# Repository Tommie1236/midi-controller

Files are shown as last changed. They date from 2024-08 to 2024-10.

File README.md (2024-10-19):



<!--[![render drawio](https://github.com/Tommie1236/midi-controller/actions/workflows/render-drawio.yml/badge.svg)](https://github.com/Tommie1236/midi-controller/actions/workflows/render-drawio.yml)-->

### huge thanks to the amazing [rp2040 skeleton project](https://github.com/daveythacher/RP2040_SKELETON). it helped immensly setting up this project. i probably couldn't have done it without

# &lt;still need good name :)&gt;
#### A lighting focused midi controller

---
### Why?
I started this project as i wanted phisical controls to go with the [mydmx3](https://www.adj.com/mydmx-3) dmx controller software.  
Mydmx3 practicly only support midi as data in/out next to dmx out. So a midi controller it is.  
There are more than enough midi controllers on the market but almost all of them are audio focused in the controls. I couldn't really vind any that i would like for controlling lighting. So i decided to design and build my own.

### Requirements
I set a couple of requirements that i definetly wanted in my controler. As following:  
#### Controls:

- **motorized faders**. Mostly for dimming controls, enough in the playback section and 1 as Master.  
  I chose motorized so they could sync with the controlling software if the value changes and for for example if you were to switch banks to a new set of controls. (mydmx doesn't support that but i wanted to design my controller to work with almost anything.)

- **Buttons**. for playbacks/executors en general control, a whole lot.  
  Of Course. what would a controller be without a lot of buttons. I also want them to have black with transparent text keycaps and rgb leds below to show the status of the button.

- **Encoders**. Mostly speed control but could also be dimmer, at least 1 per "channel"/collumn and a couple spare.
  I wanted some encoders to be able to change the speed of scene/cue playbacks. But also for for example a dimmer channel dat isn't changed often but often enough to have phisical controls for.

- **Small Displays/Scribble Strips**. channel/collumn names, one per channel/collumn.  
  To show what cue/scene was mapped to that channel/collumn. If i implement bank switching inside the controller (as mydmx doesn't support like anything. only the most basic midi triggering) i want to see what cue i have mapped on that fader/buttons.
  And maybe also to show the fader/encoder value when changing. For if you want it to a specific value and the visual position isn't enough.

- **Keypad**. just one, numbers 0-9 + some modifiers.  
  Should speak for itself. just general number inputs and modifiers.

- **"Master" Display**. (relatively) big display, just one.  
   A around 3a4" touch display for configuration of the controller and general info. Main controls for anything happening inside the controller.

- **Leds**. A lot. most RGB some just Amber.  
  I want all the buttons to have a seperate controllable RGB led to show the buttons status. and about 16 mono Amber leds around the encoders to show their value.

#### Conectivity:

- **usb midi**. one usb-B port.
  To connect to a pc running for example mydmx.

- **hardware midi**. 2 or 3 din-5 ports.
  To connect to other midi gear or any controller that has hardware midi ports on it. Should have the same data as the usb midi port

- **External Switch Ports**. 2a3 x 1/4" jack.
  To connect external footswitches or pedals. should support normal on/off footswitches and maybe one or 2 can have analog value support.

- **Desk Light**. xlr-4?.
  A xlr connector that support a lot of desk lights. preferably xlr-4 so it isn't confused with audio or dmx signals. Sadly there isn't a standard for desk ligths as far as i can find.

- **Powercon Socket**. Blue one. maybe also power out.  
  Of cource. It needs some power to run. prefereably powercon (true1??) but a C14 socket would also work.  
  with the motor faders and a lot of leds. Usb supplied power wont be enough.

#### And here are some features i want to support but arent required for the mvp: 

- **USB Hub**. Probably USB-A sockets.  
  To connect more devices downstream from the controller

- **RTP MIDI**. Wifi/Ethernet  
  Using a ESP32 or similar to handle the network stack and enable the controller to communicate either wireless or via a ethernet cable.  
  Adding to the already available midi connection options of USB-MIDI and hardware-MIDI

- **Web Server**.  
  Maybe a configuration webserver as the display will be quite small. would also run on the ESP32 that handels the network.  
  it connects to the main rp2040 using uart.

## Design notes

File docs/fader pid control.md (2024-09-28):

https://tttapa.github.io/Pages/Arduino/Control-Theory/Motor-Fader/PID-Controllers.html

currently using exactly the same values so can probably just ~~steal~~ uhmmm, use those parameters

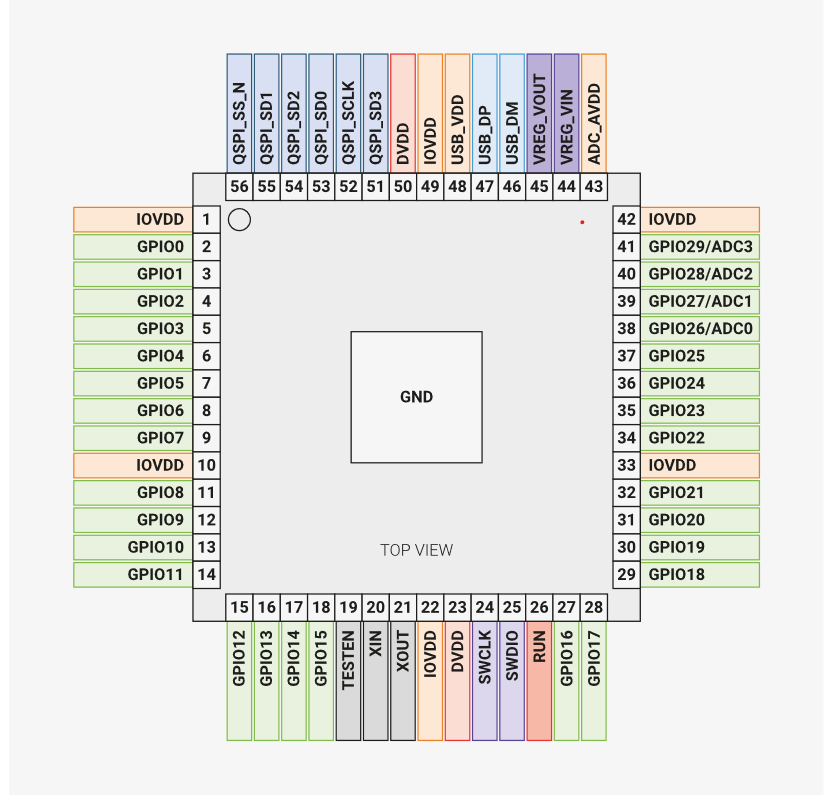
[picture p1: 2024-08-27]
docs/rp2040-pinout.png

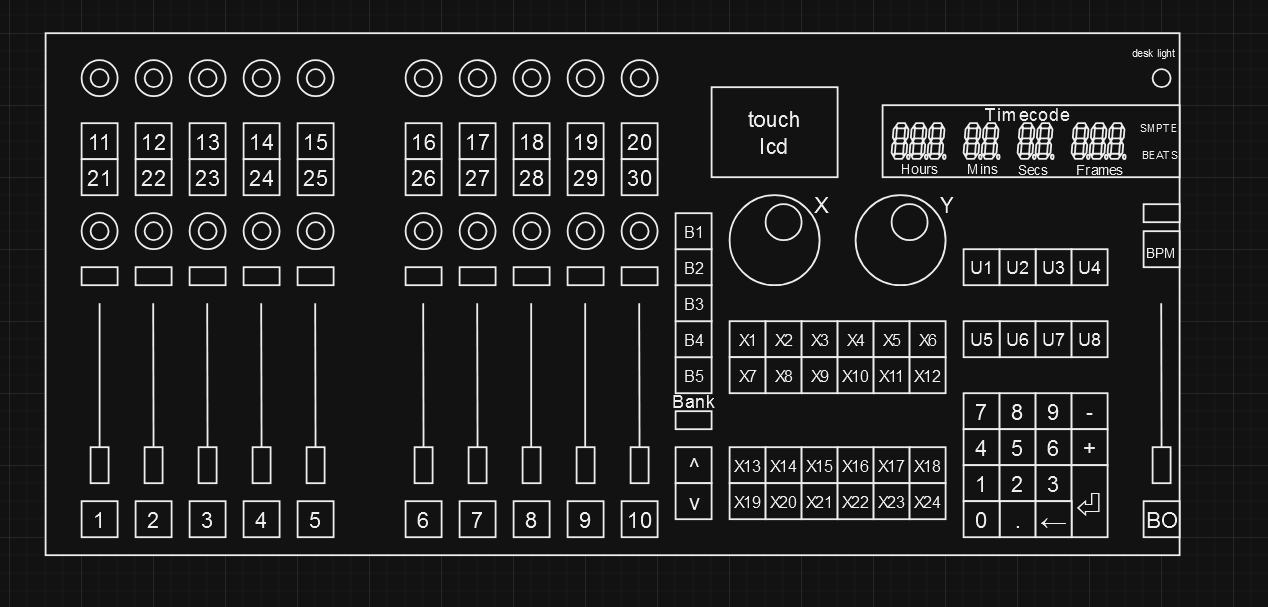
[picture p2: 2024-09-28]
model/Screenshot 2024-09-28 132856.png

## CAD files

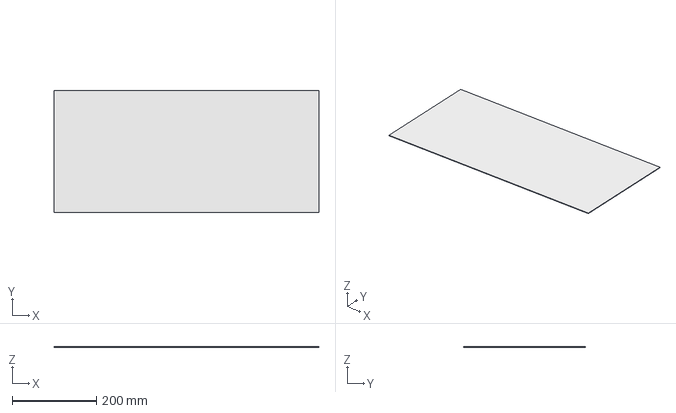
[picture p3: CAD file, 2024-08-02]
docs/model.FCStd
630.0 x 290.0 x 1.50 mm

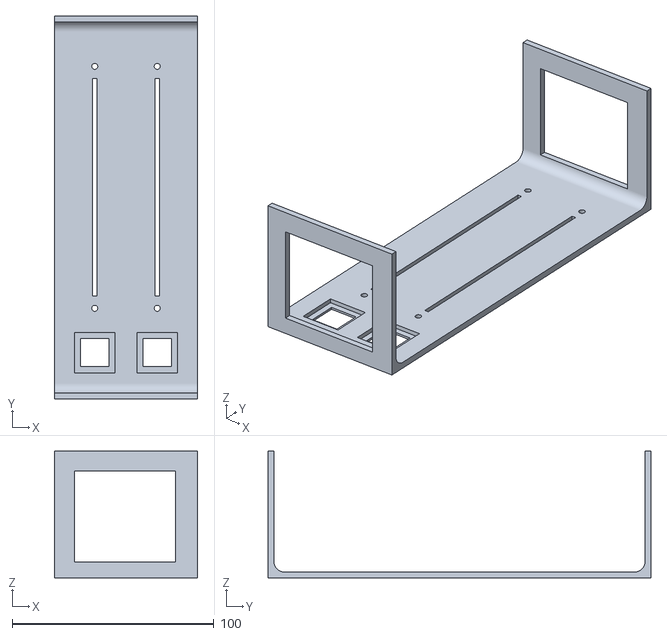
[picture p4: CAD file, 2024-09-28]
model/fader/fader test stand-Body.stl
71.0 x 190.0 x 63.0

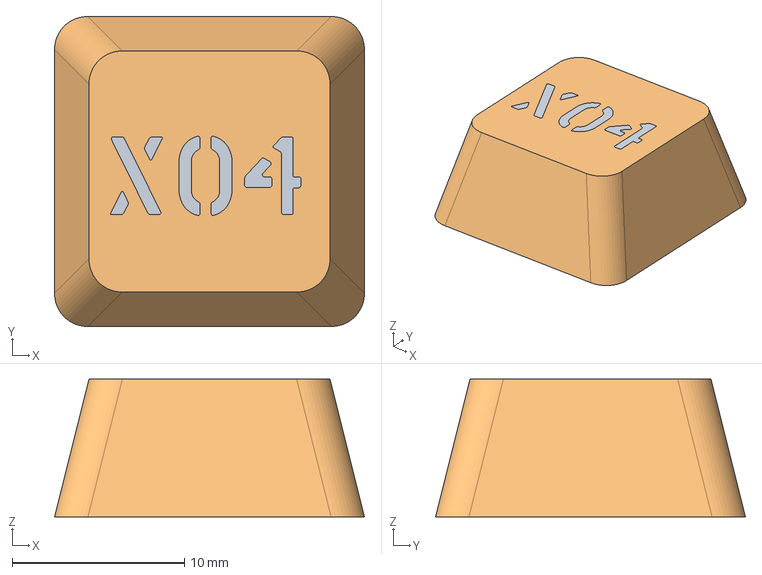
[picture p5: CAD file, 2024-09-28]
model/keycaps/keycap 1u X04.FCStd
18.0 x 18.0 x 8.00 mm

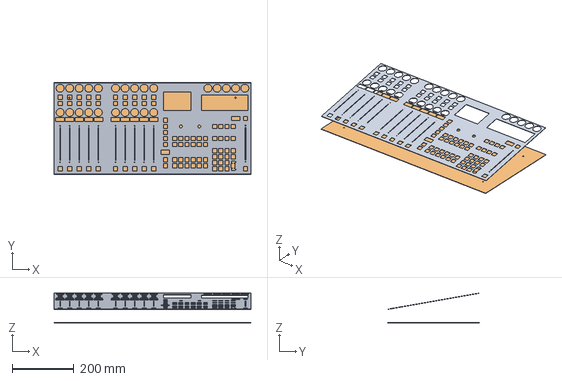
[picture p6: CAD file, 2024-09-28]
model/model.FCStd
640.0 x 300.0 x 97.0 mm
faceplate
bottom

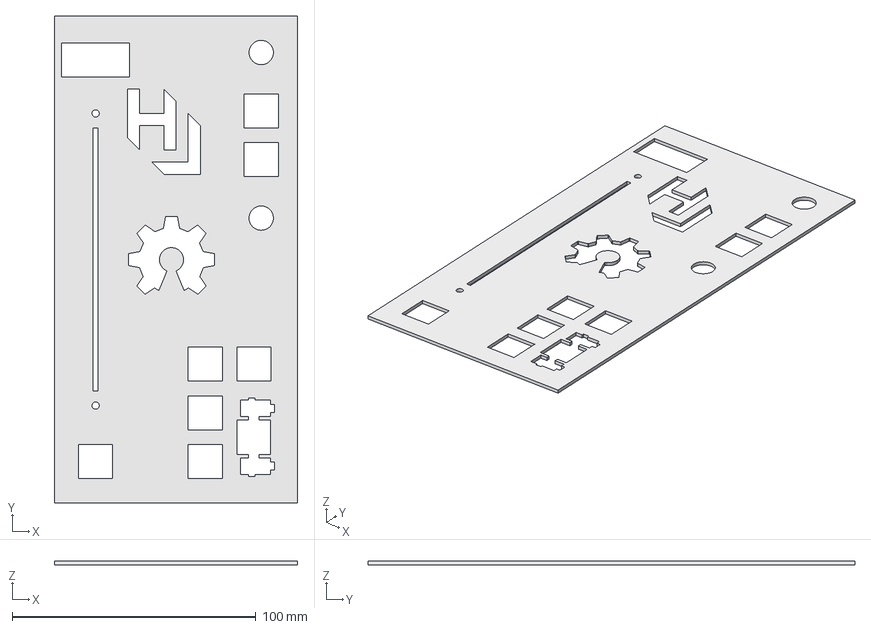
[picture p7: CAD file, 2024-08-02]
model/test/midi-test-Body.step
100.0 x 200.0 x 1.50 mm

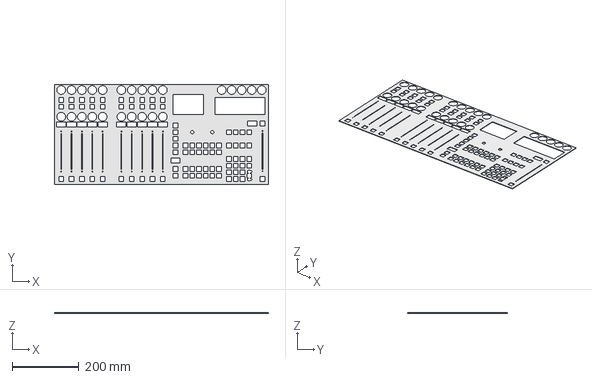
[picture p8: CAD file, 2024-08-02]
model/model-faceplate.step
640.0 x 300.0 x 1.50 mm

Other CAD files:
model/fader/fader test stand.FCStd
model/keycaps/keycap 1u X15.FCStd
model/test/midi-test.FCStd
model/keycaps/keycap 1u X12.FCStd
model/keycaps/keycap 1u X03.FCStd
model/keycaps/keycap 1u X21.FCStd
model/keycaps/keycap 1u X20.FCStd
model/keycaps/keycap 1u X05.FCStd
model/keycaps/keycap 1u X17.FCStd
model/keycaps/keycap 1u X09.FCStd
model/keycaps/keycap 1u X19.FCStd
model/keycaps/keycap 1u X10.FCStd
docs/model-old.FCStd
model/keycaps/keycap 1.stl
model/keycaps/keycap 1u +.FCStd
model/keycaps/keycap 1u -.FCStd
model/keycaps/keycap 1u 0.FCStd
model/keycaps/keycap 1u 1.FCStd
model/keycaps/keycap 1u 10.FCStd
model/keycaps/keycap 1u 11.FCStd
model/keycaps/keycap 1u 12.FCStd
model/keycaps/keycap 1u 13.FCStd
model/keycaps/keycap 1u 14.FCStd
model/keycaps/keycap 1u 15.FCStd
model/keycaps/keycap 1u 16.FCStd
model/keycaps/keycap 1u 17.FCStd
model/keycaps/keycap 1u 18.FCStd
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

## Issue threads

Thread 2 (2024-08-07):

[feature] PID control for the motor faders

Tommie1236, 2024-08-07:
motor faders barely work at half the voltage/speed they are designed for.
if run with higher than 5v (should be 10 and testing at 12) they have a difficult time reaching the correct location and just vibrate because of overshooting the location.

so speed control with pwm and if possible PID.

Tommie1236, 2024-08-22:
decided to use a separate mcu for the fader wings.
cause otherwise all the pid control/feedback had to go through 3+ levels of gpio expanders

now using something like a rp2040 on each wing that is directly connected to whatever is needed for the pid. that should also decreade the time needed/complexity for the other controls on that wing.

Tommie1236, 2024-09-04:
https://tttapa.github.io/Pages/Arduino/Control-Theory/Motor-Fader/index.html

this one uses the exact same faders as i use. so i can probably just "steal" this code and pid parameters.

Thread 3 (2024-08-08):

[calibration] faders and touchscreen.

Tommie1236, 2024-08-08:
pretty nessesary feature. especially for the display. the motor fader would be aproximately correct most of the time and isn't that big of a problem when of by a little.

calibrate with a control sequence. for the display a couple of targets to top.
for the faders put all faders to 0, 20, 50, 80, 100% and go to next value

Tommie1236, 2025-01-05:
also auto pid calibration for faders if possible

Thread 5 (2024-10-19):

TODO

Tommie1236, 2024-10-19:
-[ ] (all) add power circuitry
-[ ] (main) add sub fader board connections
-[ ] (usb) add over current sense and power switch to external usb ports
-[ ] (usb) how connect shield to gnd?
-[ ] (midi) figure out what to do with footswiches/pedal
-[ ] (fader) move display and drive circuitry to 4xx pcb, change all references in schematic/pcb
-[ ] (fader) add display backlight drivers
-[ ] (fader) add mainboard connections
-[ ] (fader) pca 9635 (u306) i2c address
-[ ] (fader) bank/bpm display connections
-[ ] (fader) update fader-encoder connections (add display dc line)
-[ ] (fader) finish routing top pcb, mainly spi bus
-[ ] (fader) how drive encoder dot leds?
-[ ] (encoder) add pcb for 5 top encoders

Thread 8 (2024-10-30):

(encoder) add pcb for 5 top encoders

Tommie1236, 2024-10-30:
- 5 push encoders
  - 15 pins, probably 1x mcp23s17.
  One spare pin. Could add one more general button. or think of specific action.
- 5 led rings (85 pins)
  - 85 pins. 6x tlc59282
  11 spare pins.

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

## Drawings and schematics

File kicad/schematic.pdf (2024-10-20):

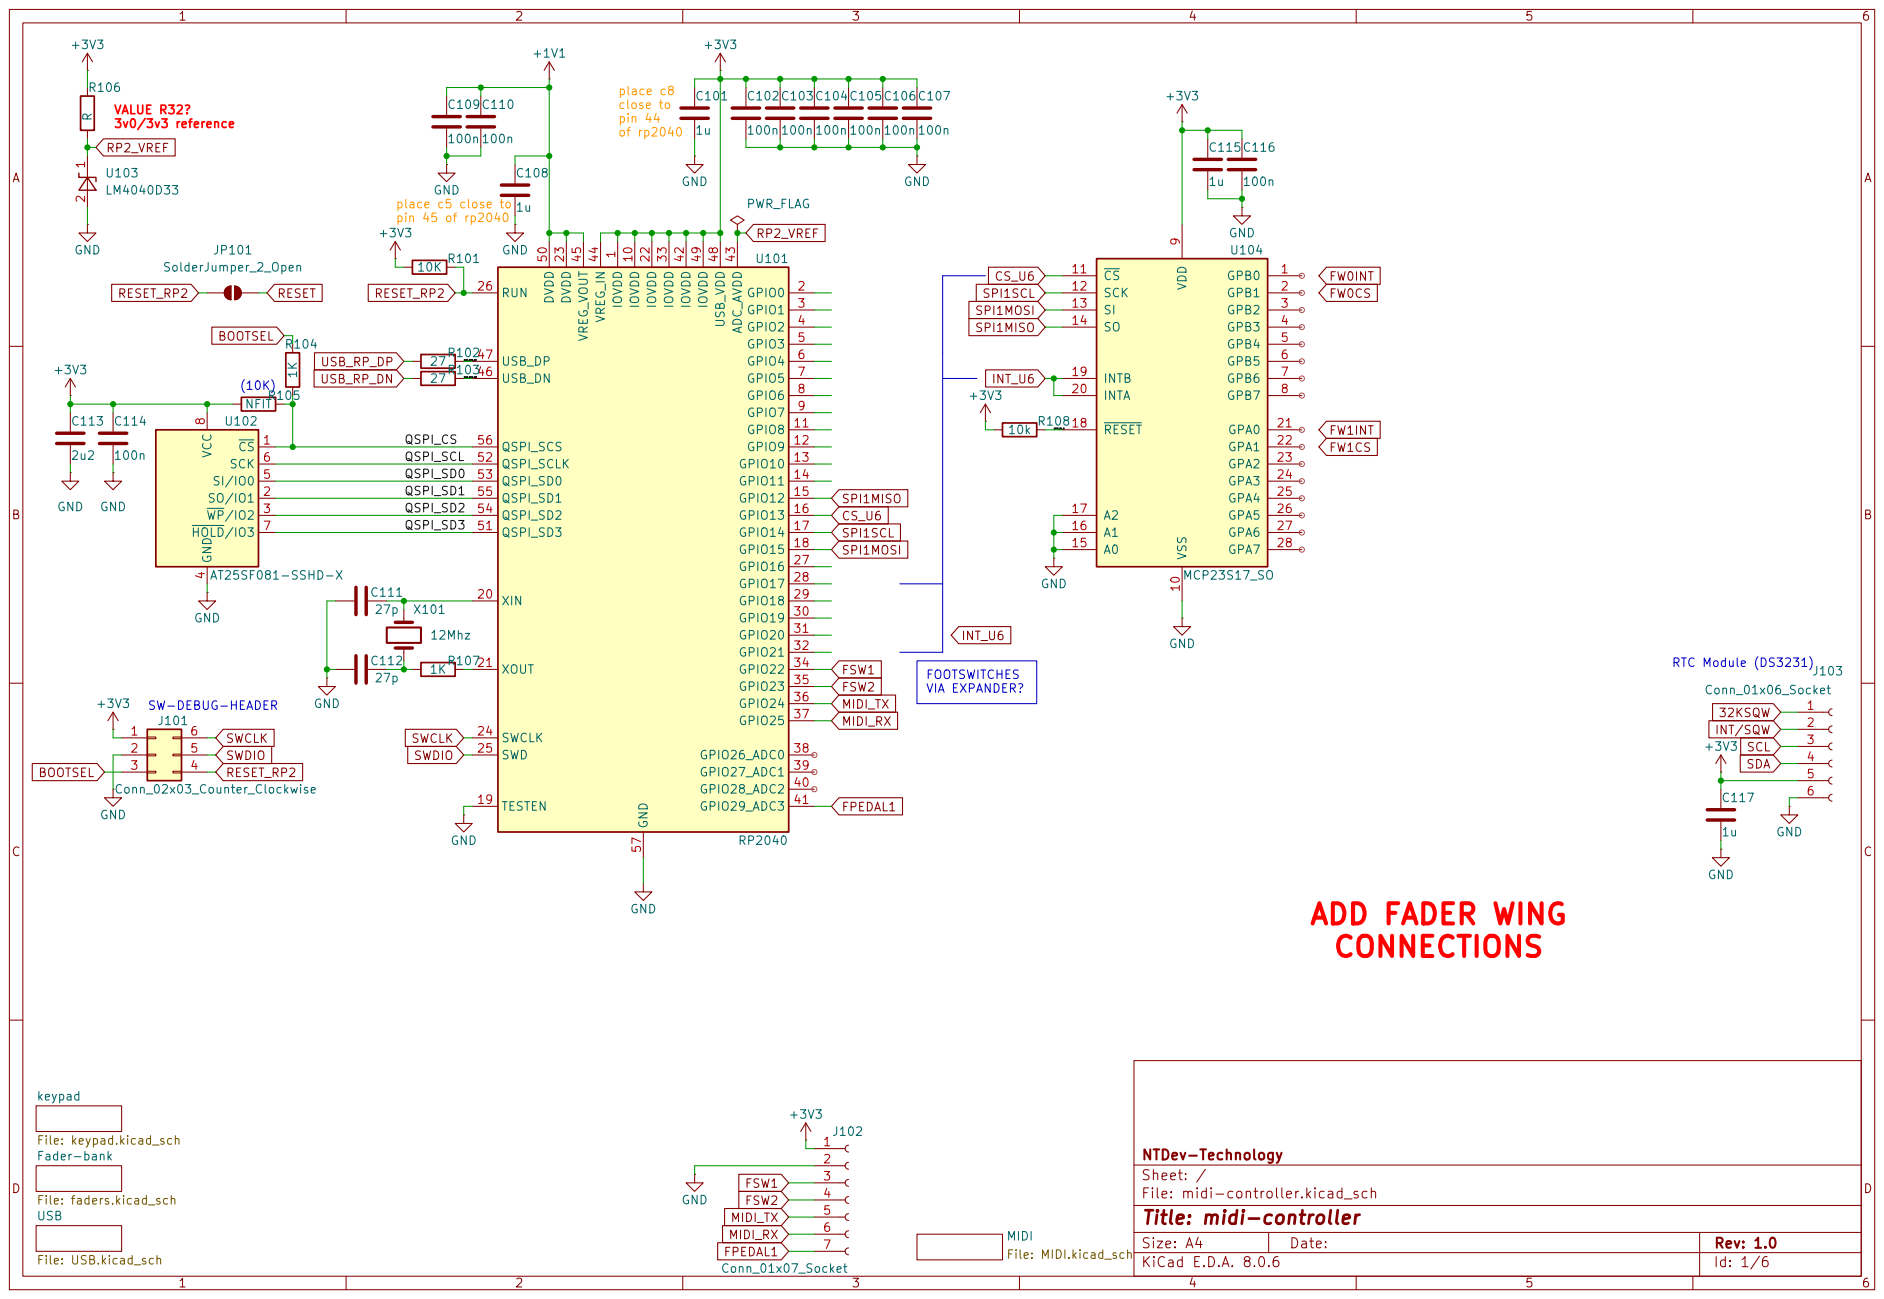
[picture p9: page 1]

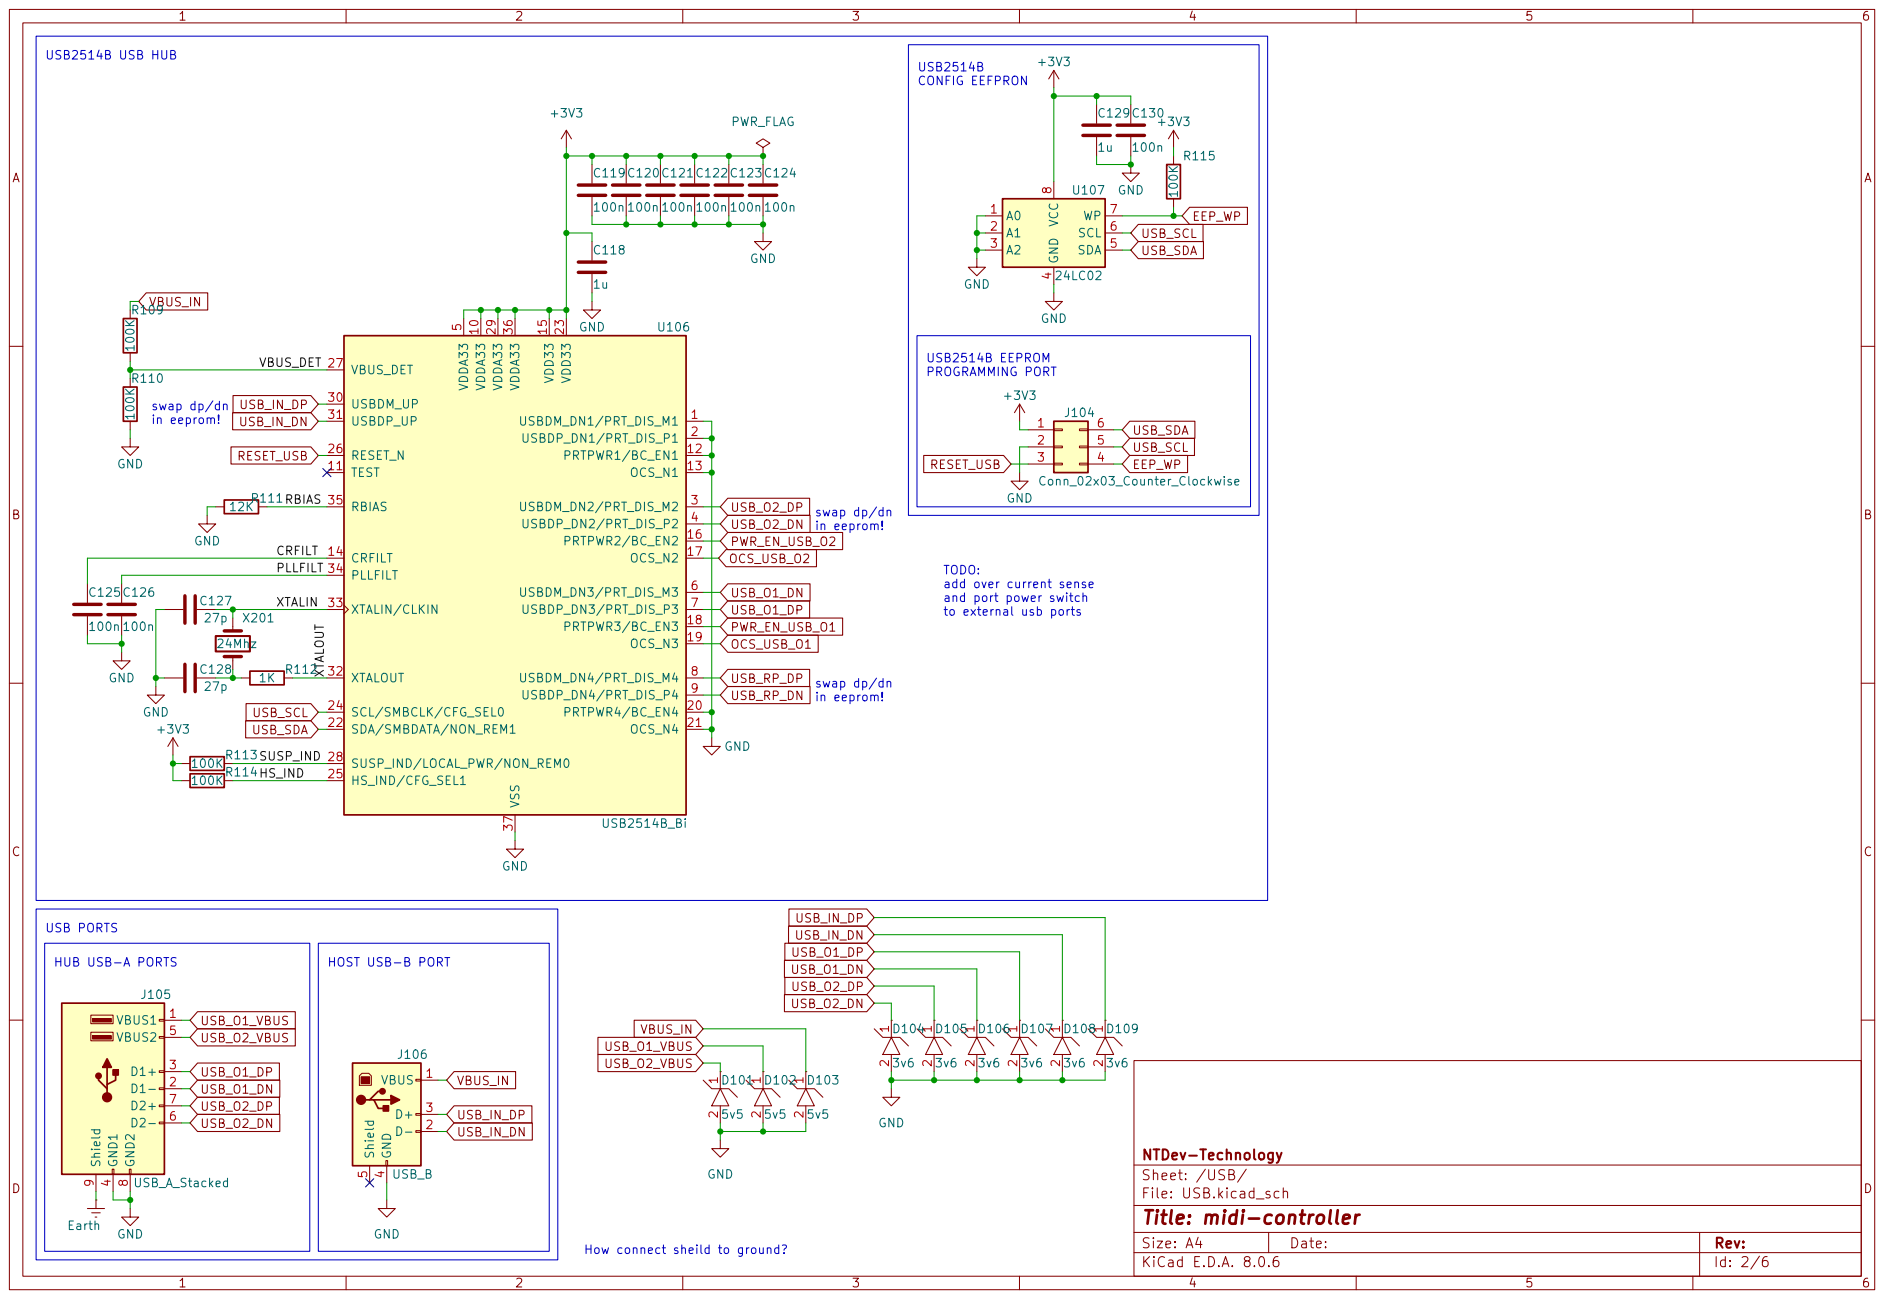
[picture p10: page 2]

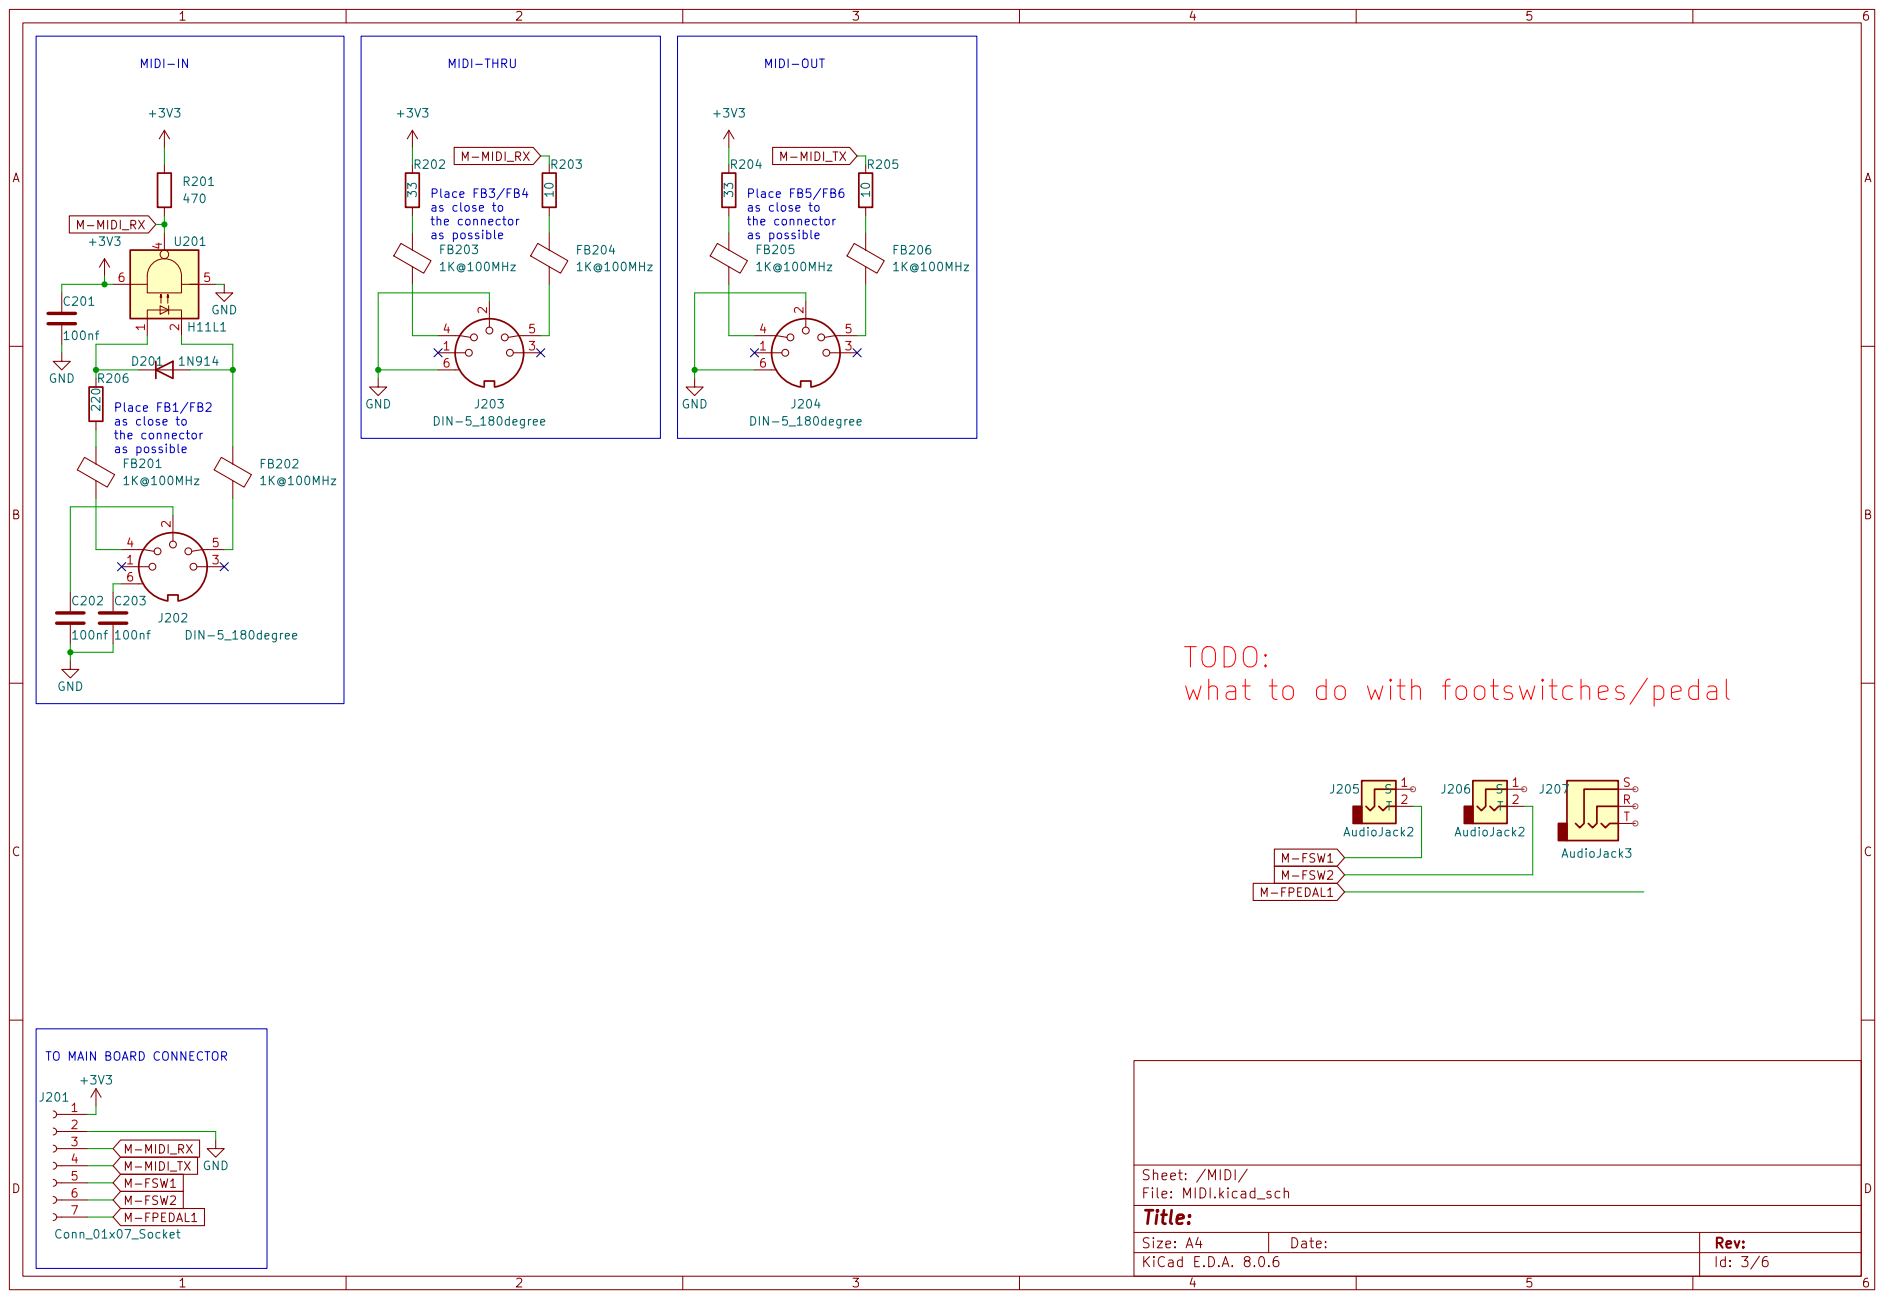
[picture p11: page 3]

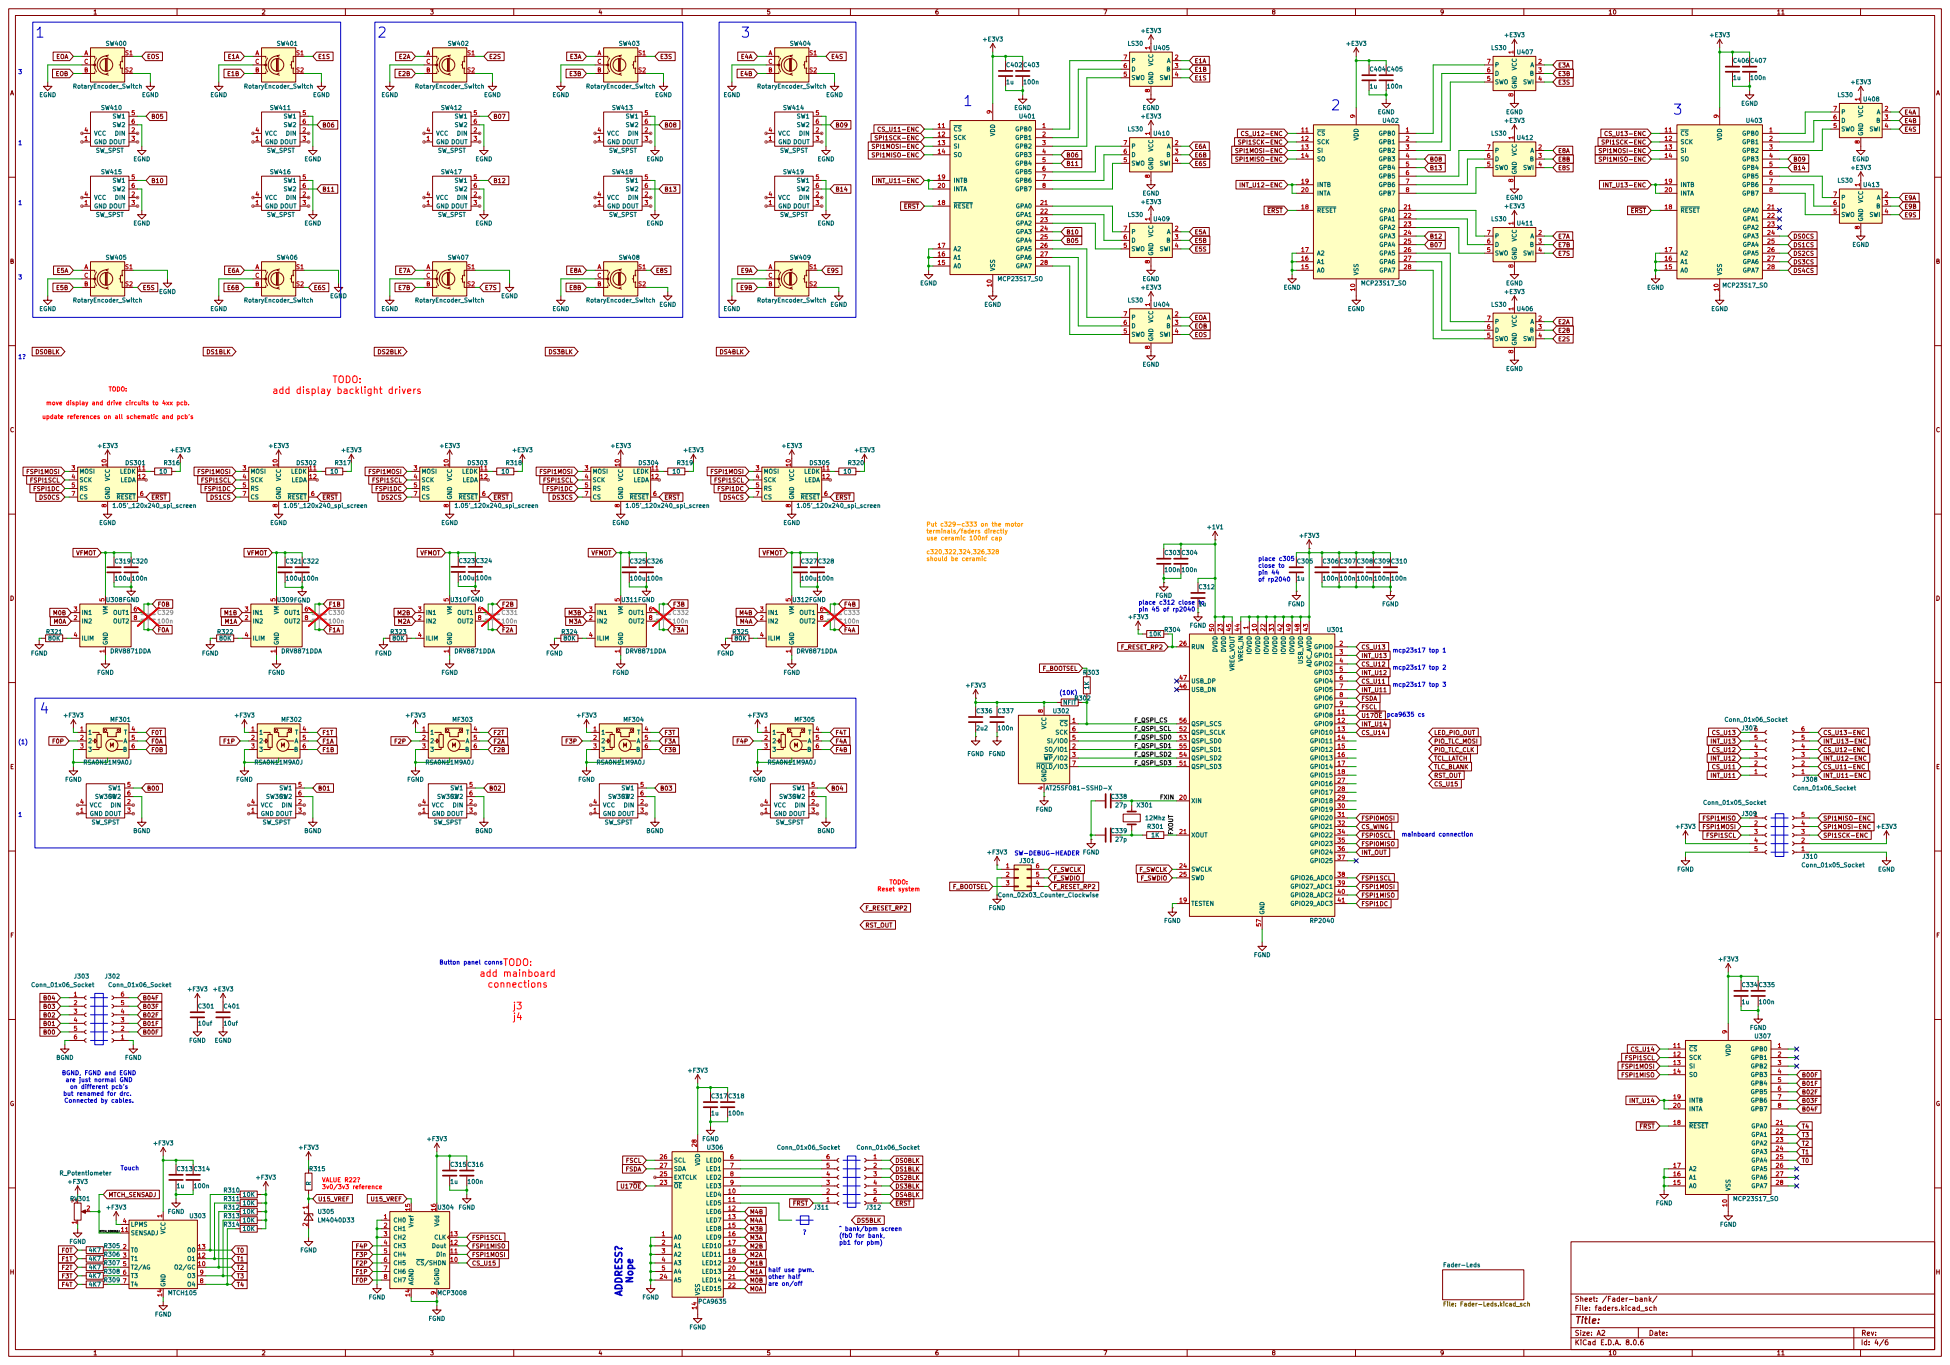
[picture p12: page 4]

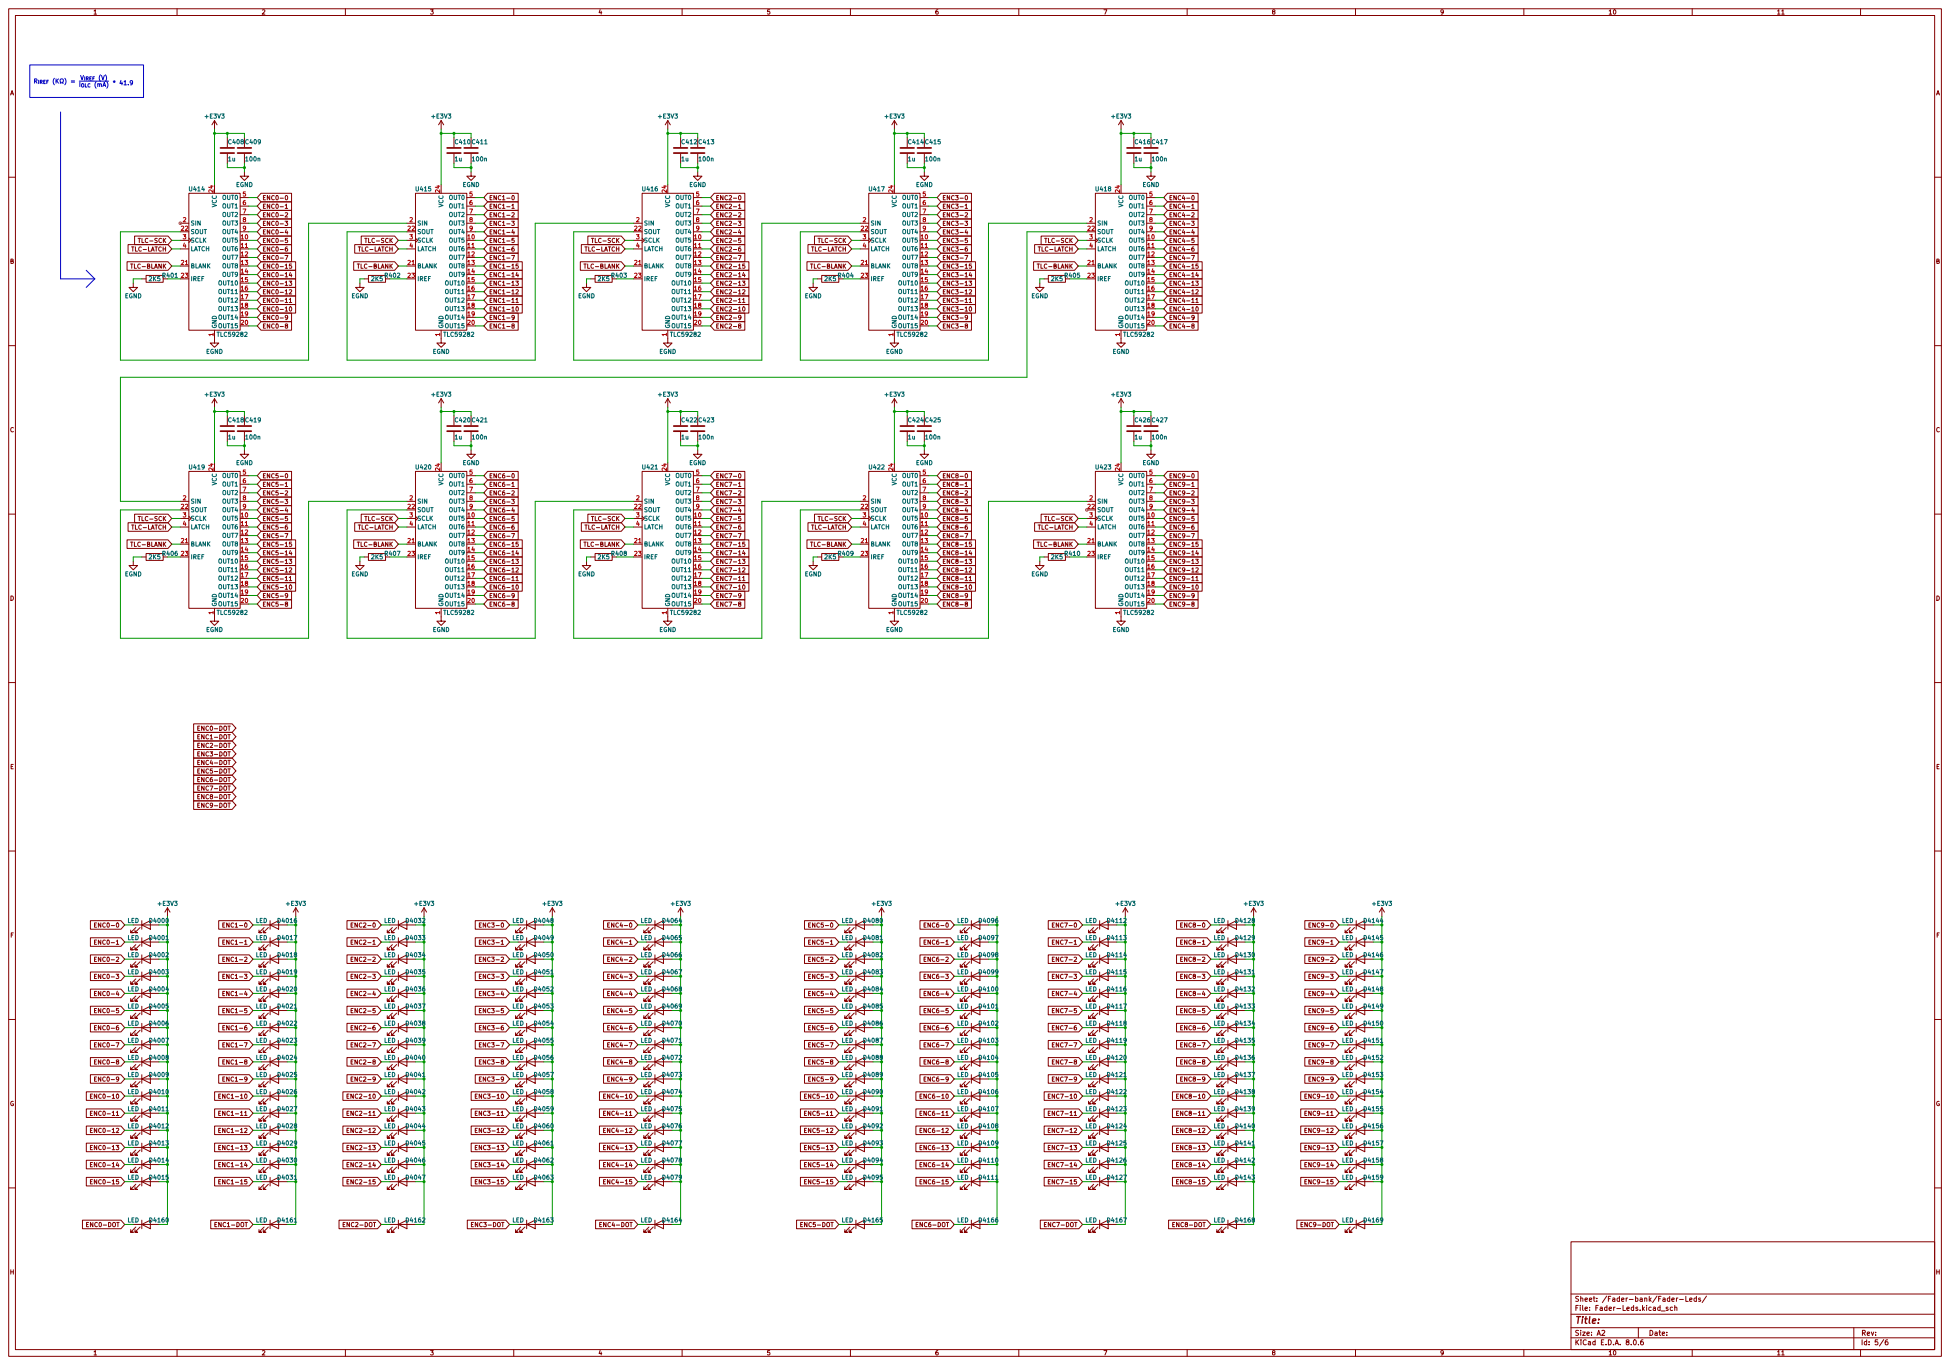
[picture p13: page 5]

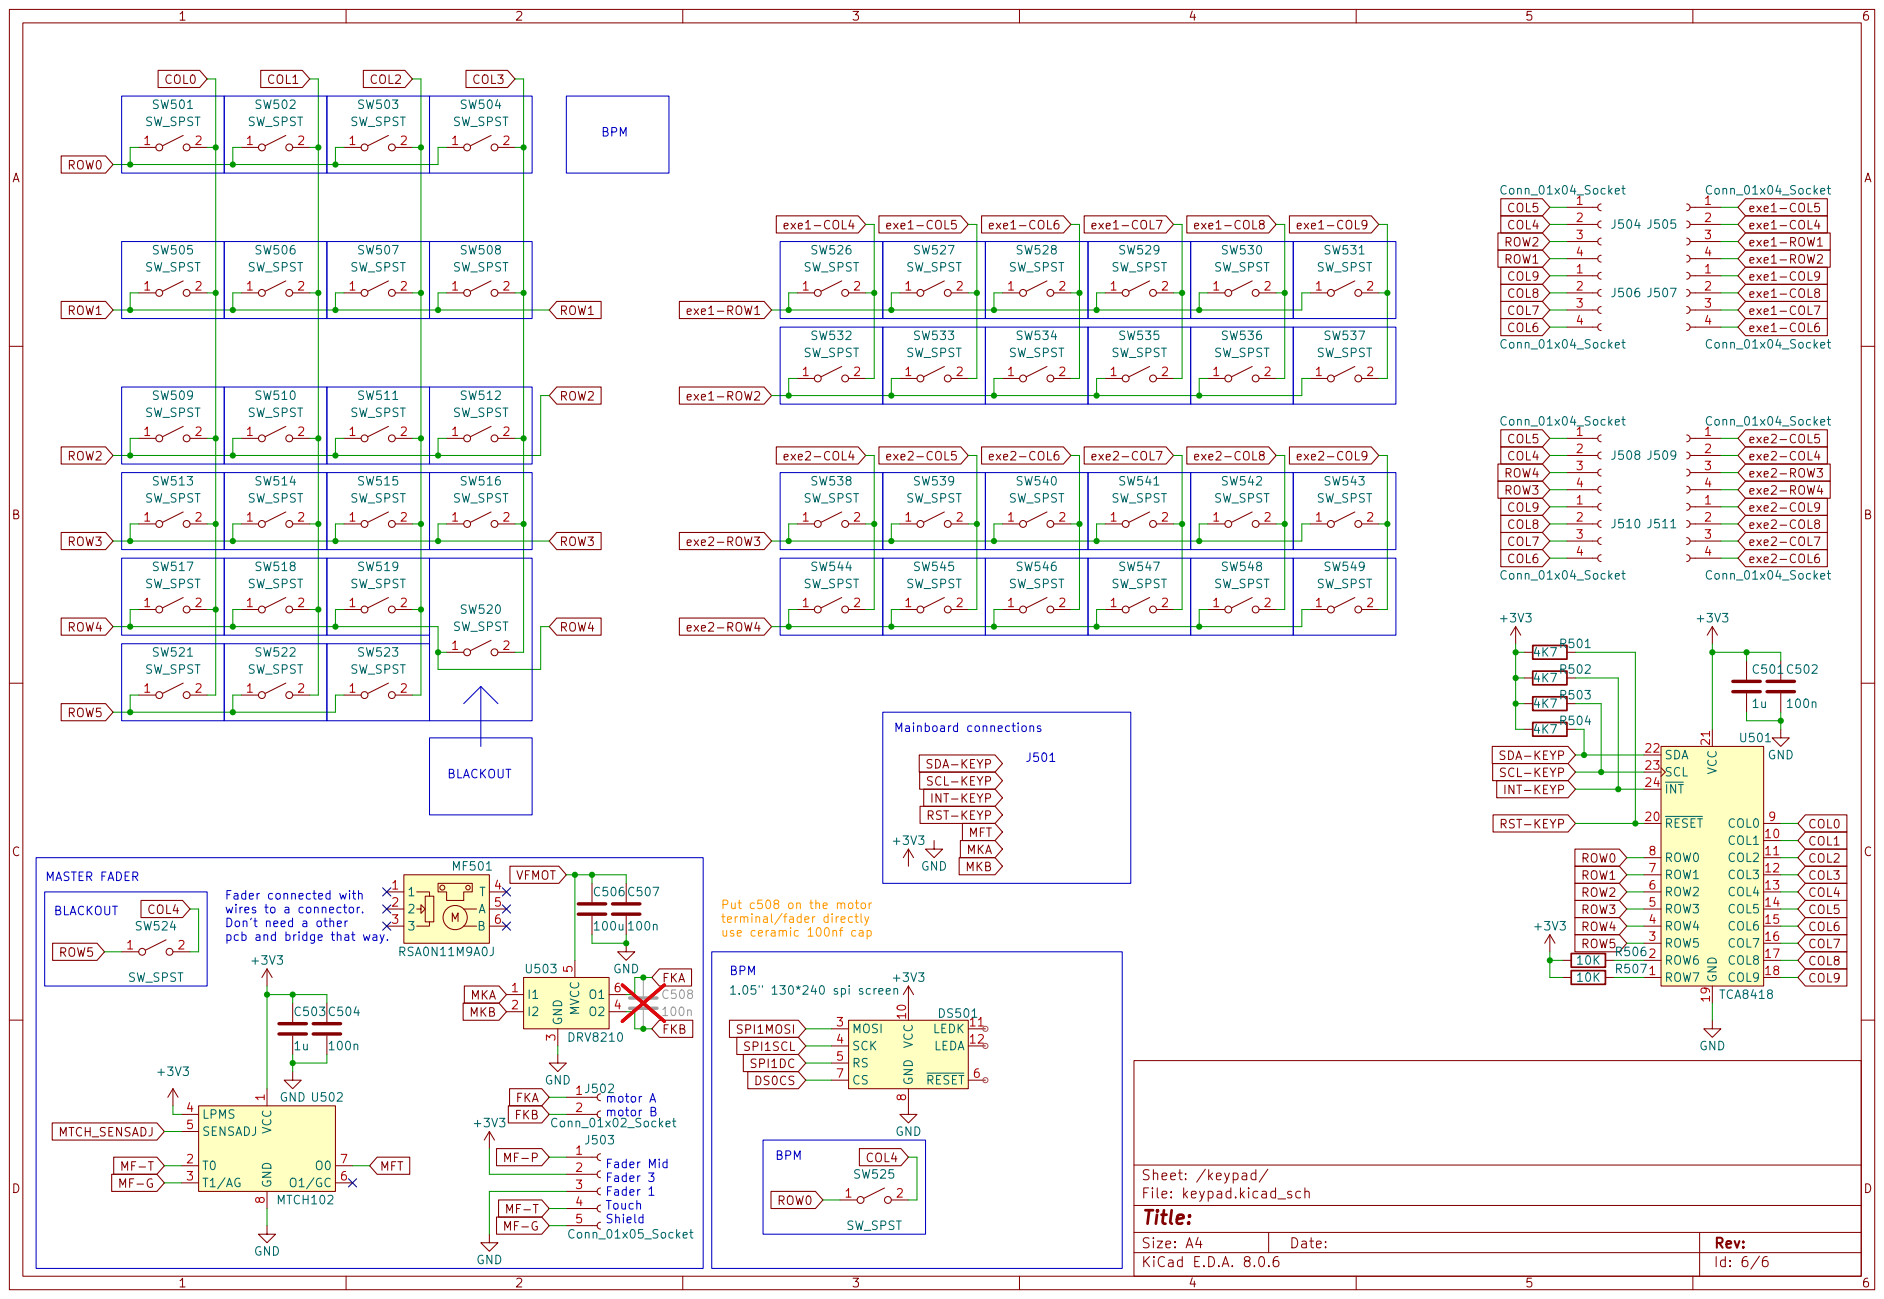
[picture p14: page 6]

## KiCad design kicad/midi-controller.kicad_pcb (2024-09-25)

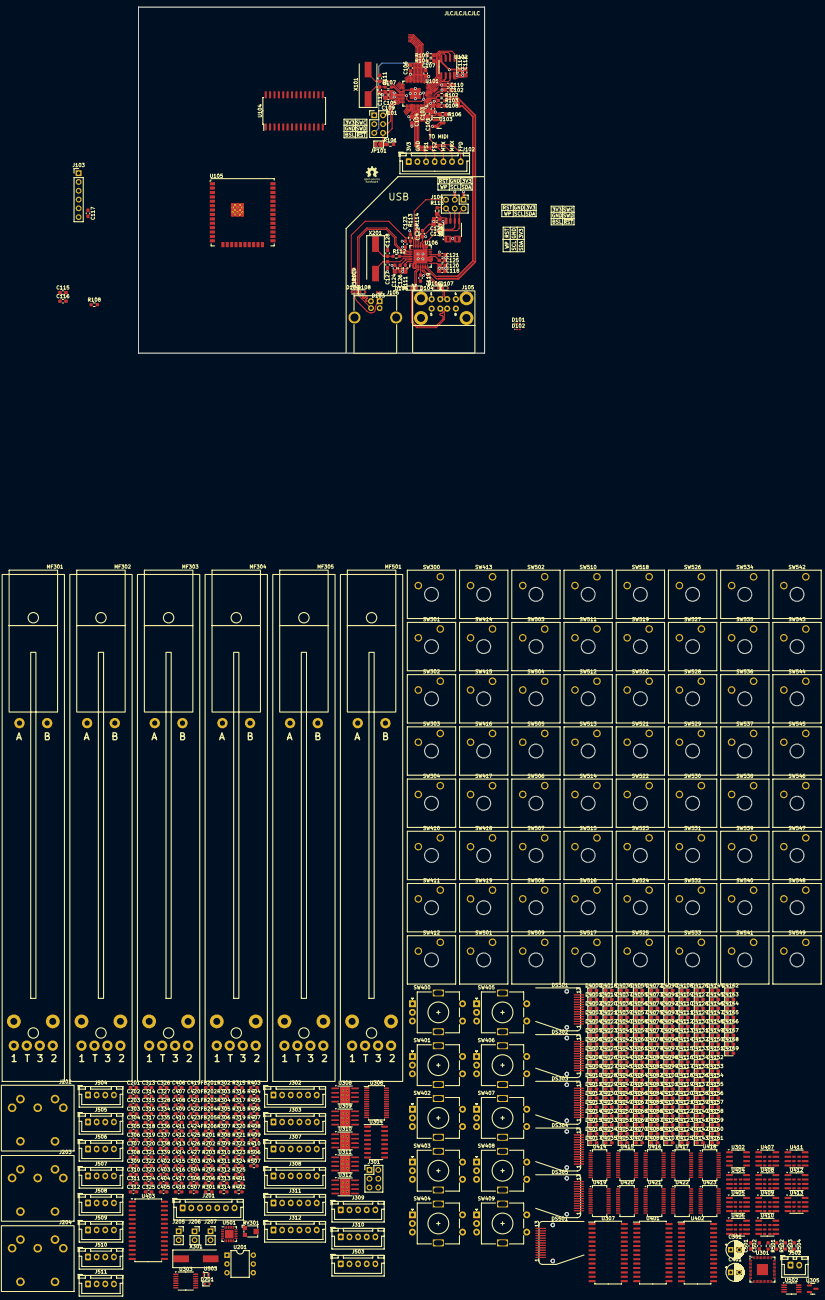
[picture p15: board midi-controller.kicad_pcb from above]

Board: 4 copper layers, 516 parts (0 on the bottom side), 480 nets.

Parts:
C101, C108, C115, C117, C118, C129, C305, C312, C313, C315, C317, C321, C323, C325, C327, C334, C402, C404, C406, C408, C410, C412, C414, C416, C418, C420, C422, C424, C426, C501, C503: 1u; C_0603_1608Metric_Pad1.08x0.95mm_HandSolder
C102, C103, C104, C105, C106, C107, C109, C110, C114, C116, C119, C120, C121, C122, C123, C124, C125, C126, C130, C303, C304, C306, C307, C308, C309, C310, C311, C314, C316, C318, C320, C322, C324, C326, C328, C335, C337, C403, C405, C407, C409, C411, C413, C415, C417, C419, C421, C423, C425, C427, C502, C504, C507: 100n; C_0603_1608Metric_Pad1.08x0.95mm_HandSolder
C111, C112, C127, C128, C338, C339: 27p; C_0603_1608Metric_Pad1.08x0.95mm_HandSolder
C113, C336: 2u2; C_0603_1608Metric_Pad1.08x0.95mm_HandSolder
C201, C202, C203: 100nf; C_0603_1608Metric_Pad1.08x0.95mm_HandSolder
C301, C401: 10uf; CP_Radial_D5.0mm_P2.50mm
C319, C506: 100u; C_0603_1608Metric_Pad1.08x0.95mm_HandSolder
D101, D102, D103: 5v5; D_0201_0603Metric_Pad0.64x0.40mm_HandSolder
D104, D105, D106, D107, D108, D109: 3v6; D_SOD-523
D201: 1N914; D_SOD-523
D4000, D4001, D4002, D4003, D4004, D4005, D4006, D4007, D4008, D4009, D4010, D4011, D4012, D4013, D4014, D4015, D4016, D4017, D4018, D4019, D4020, D4021, D4022, D4023, D4024, D4025, D4026, D4027, D4028, D4029, D4030, D4031, D4032, D4033, D4034, D4035, D4036, D4037, D4038, D4039, D4040, D4041, D4042, D4043, D4044, D4045, D4046, D4047, D4048, D4049, D4050, D4051, D4052, D4053, D4054, D4055, D4056, D4057, D4058, D4059, D4060, D4061, D4062, D4063, D4064, D4065, D4066, D4067, D4068, D4069, D4070, D4071, D4072, D4073, D4074, D4075, D4076, D4077, D4078, D4079, D4080, D4081, D4082, D4083, D4084, D4085, D4086, D4087, D4088, D4089, D4090, D4091, D4092, D4093, D4094, D4095, D4096, D4097, D4098, D4099, D4100, D4101, D4102, D4103, D4104, D4105, D4106, D4107, D4108, D4109, D4110, D4111, D4112, D4113, D4114, D4115, D4116, D4117, D4118, D4119, D4120, D4121, D4122, D4123, D4124, D4125, D4126, D4127, D4128, D4129, D4130, D4131, D4132, D4133, D4134, D4135, D4136, D4137, D4138, D4139, D4140, D4141, D4142, D4143, D4144, D4145, D4146, D4147, D4148, D4149, D4150, D4151, D4152, D4153, D4154, D4155, D4156, D4157, D4158, D4159, D4160, D4161, D4162, D4163, D4164, D4165, D4166, D4167, D4168, D4169: LED; LED_0603_1608Metric_Pad1.05x0.95mm_HandSolder
DS301, DS302, DS303, DS304, DS305: 1.05'_120x240_spi_screen; 1.05' 120x240 spi screen
DS501: 1.05" 130*240 spi screen; 1.05' 120z240 spi screen
FB201, FB202, FB203, FB204, FB205, FB206: 1K@100MHz; L_0603_1608Metric_Pad1.05x0.95mm_HandSolder
J101, J104, J301: Conn_02x03_Counter_Clockwise; PinHeader_2x03_P2.54mm_Vertical
J102, J201: Conn_01x07_Socket; JST_XH_B7B-XH-A_1x07_P2.50mm_Vertical
J103: Conn_01x06_Socket; PinHeader_1x06_P2.54mm_Vertical
J105: USB_A_Stacked; USB1035_USB-A2_STACKED
J106: USB_B; USB_B_OST_USB-B1HSxx_Horizontal
J202, J203, J204: DIN-5_180degree; DIN5-180
J205, J206: AudioJack2; PinSocket_1x02_P2.54mm_Vertical
J207: AudioJack3; PinSocket_1x02_P2.54mm_Vertical
J302, J303, J307, J308, J311, J312: Conn_01x06_Socket; JST_XH_B6B-XH-A_1x06_P2.50mm_Vertical
J309, J310, J503: Conn_01x05_Socket; JST_XH_B5B-XH-A_1x05_P2.50mm_Vertical
J502: Conn_01x02_Socket; JST_XH_B2B-XH-A_1x02_P2.50mm_Vertical
J504, J505, J506, J507, J508, J509, J510, J511: Conn_01x04_Socket; JST_XH_B4B-XH-A_1x04_P2.50mm_Vertical
JP101: SolderJumper_2_Open; SolderJumper-2_P1.3mm_Open_TrianglePad1.0x1.5mm
MF301, MF302, MF303, MF304, MF305, MF501: RSA0N11M9A0J
R101, R304, R310, R311, R312, R313, R314, R506, R507: 10K; R_0603_1608Metric_Pad0.98x0.95mm_HandSolder
R102, R103: 27; R_0603_1608Metric_Pad0.98x0.95mm_HandSolder
R104, R107, R112, R301, R303: 1K; R_0603_1608Metric_Pad0.98x0.95mm_HandSolder
R105, R302: NFIT; R_0603_1608Metric_Pad0.98x0.95mm_HandSolder
R106, R315: R; R_0603_1608Metric_Pad0.98x0.95mm_HandSolder
R108: 10k; R_0603_1608Metric_Pad0.98x0.95mm_HandSolder
R109, R110, R113, R114, R115: 100K; R_0603_1608Metric_Pad0.98x0.95mm_HandSolder
R111: 12K; R_0603_1608Metric_Pad0.98x0.95mm_HandSolder
R201: 470; R_0603_1608Metric_Pad0.98x0.95mm_HandSolder
R202, R204: 33; R_0603_1608Metric_Pad0.98x0.95mm_HandSolder
R203, R205, R316, R317, R318, R319, R320: 10; R_0603_1608Metric_Pad0.98x0.95mm_HandSolder
R206: 220; R_0603_1608Metric_Pad0.98x0.95mm_HandSolder
R305, R306, R307, R308, R309, R501, R502, R503, R504: 4K7; R_0603_1608Metric_Pad0.98x0.95mm_HandSolder
R321, R322, R323, R324, R325: 80K; R_0603_1608Metric_Pad0.98x0.95mm_HandSolder
R401, R402, R403, R404, R405, R406, R407, R408, R409, R410: 2K5; R_0603_1608Metric_Pad0.98x0.95mm_HandSolder
RV301: R_Potentiometer; Potentiometer_Bourns_TC33X_Vertical
SW300, SW301, SW302, SW303, SW304, SW410, SW411, SW412, SW413, SW414, SW415, SW416, SW417, SW418, SW419, SW501, SW502, SW503, SW504, SW505, SW506, SW507, SW508, SW509, SW510, SW511, SW512, SW513, SW514, SW515, SW516, SW517, SW518, SW519, SW521, SW522, SW523, SW524, SW525, SW526, SW527, SW528, SW529, SW530, SW531, SW532, SW533, SW534, SW535, SW536, SW537, SW538, SW539, SW540, SW541, SW542, SW543, SW544, SW545, SW546, SW547, SW548, SW549: SW_SPST; SW_Cherry_MX_1.00u_Plate
SW400, SW401, SW402, SW403, SW404, SW405, SW406, SW407, SW408, SW409: RotaryEncoder_Switch; RotaryEncoder_Alps_EC11E-Switch_Vertical_H20mm
SW520: SW_SPST; SW_Cherry_MX_2.00u_Vertical_Plate
U101, U301: RP2040; QFN-56-1EP_7x7mm_P0.4mm_EP3.2x3.2mm
U102, U302: AT25SF081-SSHD-X; SOIC-8_3.9x4.9mm_P1.27mm
U103, U305: LM4040D33; SOT-23
U104, U307, U401, U402, U403: MCP23S17_SO; SOIC-28W_7.5x17.9mm_P1.27mm
U105: ESP32-WROOM-32U
U106: USB2514B_Bi; QFN-36-1EP_6x6mm_P0.5mm_EP4.1x4.1mm
U107: 24LC02; SOP-8_3.9x4.9mm_P1.27mm
U201: H11L1; DIP-6_W7.62mm
U303: MTCH105; TSSOP-14_4.4x5mm_P0.65mm
U304: MCP3008; SOIC-16_3.9x9.9mm_P1.27mm
U306: PCA9635; TSSOP-28_4.4x9.7mm_P0.65mm
U308, U309, U310, U311, U312: DRV8871DDA; Texas_HTSOP-8-1EP_3.9x4.9mm_P1.27mm_EP2.95x4.9mm_Mask2.4x3.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
U404, U405, U406, U407, U408, U409, U410, U411, U412, U413: LS30; SOIC-8_3.9x4.9mm_P1.27mm
U414, U415, U416, U417, U418, U419, U420, U421, U422, U423: TLC59282; SSOP-24_3.9x8.7mm_P0.635mm
U501: TCA8418; WQFN-24-1EP_4x4mm_P0.5mm_EP2.45x2.45mm
U502: MTCH102; MSOP-8_3x3mm_P0.65mm
U503: DRV8210; SOT-6
X101, X301: 12Mhz; Crystal_SMD_HC49-SD
X201: 24Mhz; Crystal_SMD_HC49-SD

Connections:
+1V1: C108.1, C109.1, C110.1, C303.1, C304.1, C312.1, U101.23 (DVDD), U101.45 (VREG_VOUT), U101.50 (DVDD), U301.23 (DVDD), U301.45 (VREG_VOUT), U301.50 (DVDD)
+3V3: C101.1, C102.1, C103.1, C104.1, C105.1, C106.1, C107.1, C113.1, C114.1, C115.1, C116.1, C117.1, C118.1, C119.1, C120.1, C121.1, C122.1, C123.1, C124.1, C129.1, C130.1, C201.1, C501.1, C502.1, C503.1, C504.1, DS501.10 (VCC), J101.1, J102.1, J103.5, J104.1, J201.1, J503.2, R101.1, R105.1, R106.1, R108.1, R113.1, R114.1, R115.1, R201.2, R202.2, R204.2, R501.1, R502.1, R503.1, R504.1, R506.1, R507.1, U101.1 (IOVDD), U101.10 (IOVDD), U101.22 (IOVDD), U101.33 (IOVDD), U101.42 (IOVDD), U101.44 (VREG_IN), U101.48 (USB_VDD), U101.49 (IOVDD), U102.8 (VCC), U104.9 (VDD), U106.5 (VDDA33), U106.10 (VDDA33), U106.15 (VDD33), U106.23 (VDD33), U106.29 (VDDA33), U106.36 (VDDA33), U107.8 (VCC), U201.6, U501.21 (VCC), U502.1 (VCC), U502.4 (LPMS)
+E3V3: C401.1, C402.1, C403.1, C404.1, C405.1, C406.1, C407.1, C408.1, C409.1, C410.1, C411.1, C412.1, C413.1, C414.1, C415.1, C416.1, C417.1, C420.1, C421.1, C422.1, C423.1, C424.1, C425.1, C426.1, C427.1, D4000.2 (A), D4001.2 (A), D4002.2 (A), D4003.2 (A), D4004.2 (A), D4005.2 (A), D4006.2 (A), D4007.2 (A), D4008.2 (A), D4009.2 (A), D4010.2 (A), D4011.2 (A), D4012.2 (A), D4013.2 (A), D4014.2 (A), D4015.2 (A), D4016.2 (A), D4017.2 (A), D4018.2 (A), D4019.2 (A), D4020.2 (A), D4021.2 (A), D4022.2 (A), D4023.2 (A), D4024.2 (A), D4025.2 (A), D4026.2 (A), D4027.2 (A), D4028.2 (A), D4029.2 (A), D4030.2 (A), D4031.2 (A), D4032.2 (A), D4033.2 (A), D4034.2 (A), D4035.2 (A), D4036.2 (A), D4037.2 (A), D4038.2 (A), D4039.2 (A), D4040.2 (A), D4041.2 (A), D4042.2 (A), D4043.2 (A), D4044.2 (A), D4045.2 (A), D4046.2 (A), D4047.2 (A), D4048.2 (A), D4049.2 (A), D4050.2 (A), D4051.2 (A), D4052.2 (A), D4053.2 (A), D4054.2 (A), D4055.2 (A), D4056.2 (A), D4057.2 (A), D4058.2 (A), D4059.2 (A), D4060.2 (A), D4061.2 (A), D4062.2 (A), D4063.2 (A), D4064.2 (A), D4065.2 (A), D4066.2 (A), D4067.2 (A), D4068.2 (A), D4069.2 (A), D4070.2 (A), D4071.2 (A), D4072.2 (A), D4073.2 (A), D4074.2 (A), D4075.2 (A), D4076.2 (A), D4077.2 (A), D4078.2 (A), D4079.2 (A), D4080.2 (A), D4081.2 (A), D4082.2 (A), D4083.2 (A), D4084.2 (A), D4085.2 (A), D4086.2 (A), D4087.2 (A), D4088.2 (A), D4089.2 (A), D4090.2 (A), D4091.2 (A), D4092.2 (A), D4093.2 (A), D4094.2 (A), D4095.2 (A), D4112.2 (A), D4113.2 (A), D4114.2 (A), D4115.2 (A), D4116.2 (A), D4117.2 (A), D4118.2 (A), D4119.2 (A), D4120.2 (A), D4121.2 (A), D4122.2 (A), D4123.2 (A), D4124.2 (A), D4125.2 (A), D4126.2 (A), D4127.2 (A), D4128.2 (A), D4129.2 (A), D4130.2 (A), D4131.2 (A), D4132.2 (A), D4133.2 (A), D4134.2 (A), D4135.2 (A), D4136.2 (A), D4137.2 (A), D4138.2 (A), D4139.2 (A), D4140.2 (A), D4141.2 (A), D4142.2 (A), D4143.2 (A), D4144.2 (A), D4145.2 (A), D4146.2 (A), D4147.2 (A), D4148.2 (A), D4149.2 (A), D4150.2 (A), D4151.2 (A), D4152.2 (A), D4153.2 (A), D4154.2 (A), D4155.2 (A), D4156.2 (A), D4157.2 (A), D4158.2 (A), D4159.2 (A), D4160.2 (A), D4161.2 (A), D4162.2 (A), D4163.2 (A), D4164.2 (A), D4165.2 (A), D4167.2 (A), D4168.2 (A), D4169.2 (A), DS301.10 (VCC), DS302.10 (VCC), DS303.10 (VCC), DS304.10 (VCC), DS305.10 (VCC), J310.2, R316.2, R317.2, R318.2, R319.2, R320.2, U401.9 (VDD), U402.9 (VDD), U403.9 (VDD), U404.1 (VCC), U405.1 (VCC), U406.1 (VCC), U407.1 (VCC), U408.1 (VCC), U409.1 (VCC), U410.1 (VCC), U411.1 (VCC), U412.1 (VCC), U413.1 (VCC), U414.24 (VCC), U415.24 (VCC), U416.24 (VCC), U417.24 (VCC), U418.24 (VCC), U420.24 (VCC), U421.24 (VCC), U422.24 (VCC), U423.24 (VCC)
+F3V3: C301.1, C305.1, C306.1, C307.1, C308.1, C309.1, C310.1, C311.1, C313.1, C314.1, C315.1, C316.1, C317.1, C318.1, C334.1, C335.1, C336.1, C337.1, J301.1, J309.4, MF301.1, MF302.1, MF303.1, MF304.1, MF305.1, R302.1, R304.1, R310.2, R311.2, R312.2, R313.2, R314.2, R315.1, U301.1 (IOVDD), U301.10 (IOVDD), U301.22 (IOVDD), U301.33 (IOVDD), U301.42 (IOVDD), U301.44 (VREG_IN), U301.48 (USB_VDD), U301.49 (IOVDD), U302.8 (VCC), U303.1 (VCC), U303.4 (LPMS), U304.16 (Vdd), U306.28 (VDD), U307.9 (VDD)
/Fader-bank/FXIN: C338.2, U301.20 (XIN), X301.2
/Fader-bank/FXOUT: R301.2, U301.21 (XOUT)
/Fader-bank/F_QSPI_CS: R302.2, R303.1, U301.56 (QSPI_SCS), U302.1 (~CS)
/Fader-bank/F_QSPI_SCL: U301.52 (QSPI_SCLK), U302.6 (SCK)
/Fader-bank/F_QSPI_SD0: U301.53 (QSPI_SD0), U302.5 (SI/IO0)
/Fader-bank/F_QSPI_SD1: U301.55 (QSPI_SD1), U302.2 (SO/IO1)
/Fader-bank/F_QSPI_SD2: U301.54 (QSPI_SD2), U302.3 (~WP/IO2)
/Fader-bank/F_QSPI_SD3: U301.51 (QSPI_SD3), U302.7 (~HOLD/IO3)
/QSPI_CS: R104.1, R105.2, U101.56 (QSPI_SCS), U102.1 (~CS)
/QSPI_SCL: U101.52 (QSPI_SCLK), U102.6 (SCK)
/QSPI_SD0: U101.53 (QSPI_SD0), U102.5 (SI/IO0)
/QSPI_SD1: U101.55 (QSPI_SD1), U102.2 (SO/IO1)
/QSPI_SD2: U101.54 (QSPI_SD2), U102.3 (~WP/IO2)
/QSPI_SD3: U101.51 (QSPI_SD3), U102.7 (~HOLD/IO3)
/SPI0_01_R: R108.2, U104.18 (~RESET)
/USB/CRFILT: C125.1, U106.14 (CRFILT)
/USB/HS_IND: R114.2, U106.25 (HS_IND/CFG_SEL1)
/USB/PLLFILT: C126.1, U106.34 (PLLFILT)
/USB/RBIAS: R111.2, U106.35 (RBIAS)
/USB/SUSP_IND: R113.2, U106.28 (SUSP_IND/LOCAL_PWR/NON_REM0)
/USB/VBUS_DET: R109.2, R110.1, U106.27 (VBUS_DET)
/USB/XTALIN: C127.2, U106.33 (XTALIN/CLKIN), X201.2
/USB/XTALOUT: R112.2, U106.32 (XTALOUT)
/USB_RP2_DN: R103.2, U101.46 (USB_DN)
/USB_RP2_DP: R102.2, U101.47 (USB_DP)
B00: J303.5, SW300.2 (B)
B00F: J302.2, U307.4 (GPB3)
B01: J303.4, SW301.2 (B)
B01F: J302.3, U307.5 (GPB4)
B02: J303.3, SW302.2 (B)
B02F: J302.4, U307.6 (GPB5)
B03: J303.2, SW303.2 (B)
B03F: J302.5, U307.7 (GPB6)
B04: J303.1, SW304.2 (B)
B04F: J302.6, U307.8 (GPB7)
B05: SW410.2 (B), U401.25 (GPA4)
B06: SW411.1 (A), U401.4 (GPB3)
B07: SW412.2 (B), U402.25 (GPA4)
B08: SW413.1 (A), U402.4 (GPB3)
B09: SW414.1 (A), U403.4 (GPB3)
B10: SW415.2 (B), U401.24 (GPA3)
B11: SW416.1 (A), U401.5 (GPB4)
B12: SW417.2 (B), U402.24 (GPA3)
B13: SW418.1 (A), U402.5 (GPB4)
B14: SW419.1 (A), U403.5 (GPB4)
BGND: J303.6, SW300.1 (A), SW301.1 (A), SW302.1 (A), SW303.1 (A), SW304.1 (A)
BOOTSEL: J101.3, R104.2
COL0: SW501.2 (B), SW505.2 (B), SW509.2 (B), SW513.2 (B), SW517.2 (B), SW521.2 (B), U501.9 (COL0)
COL1: SW502.2 (B), SW506.2 (B), SW510.2 (B), SW514.2 (B), SW518.2 (B), SW522.2 (B), U501.10 (COL1)
COL2: SW503.2 (B), SW507.2 (B), SW511.2 (B), SW515.2 (B), SW519.2 (B), SW523.2 (B), U501.11 (COL2)
COL3: SW504.2 (B), SW508.2 (B), SW512.2 (B), SW516.2 (B), SW520.2 (B), U501.12 (COL3)
COL4: J504.2, J508.2, SW524.2 (B), SW525.2 (B), U501.13 (COL4)
COL5: J504.1, J508.1, U501.14 (COL5)
COL6: J506.4, J510.4, U501.15 (COL6)
COL7: J506.3, J510.3, U501.16 (COL7)
COL8: J506.2, J510.2, U501.17 (COL8)
COL9: J506.1, J510.1, U501.18 (COL9)
CS_U6: U101.16 (GPIO13), U104.11 (~CS)
CS_U11: J307.2, U301.6 (GPIO4)
CS_U11-ENC: J308.2, U401.11 (~CS)
CS_U12: J307.4, U301.4 (GPIO2)
CS_U12-ENC: J308.4, U402.11 (~CS)
CS_U13: J307.6, U301.2 (GPIO0)
CS_U13-ENC: J308.6, U403.11 (~CS)
CS_U14: U301.13 (GPIO10), U307.11 (~CS)
DS0CS: DS301.7 (CS), DS501.7 (CS), U403.24 (GPA3)
DS1CS: DS302.7 (CS), U403.25 (GPA4)
DS2CS: DS303.7 (CS), U403.26 (GPA5)
DS3CS: DS304.7 (CS), U403.27 (GPA6)
DS4CS: DS305.7 (CS), U403.28 (GPA7)
E1A: SW401.A, U405.2 (A)
E1B: SW401.B, U405.3 (B)
E1S: SW401.S1, U405.4 (SWI)
E2A: SW402.A, U406.2 (A)
E2B: SW402.B, U406.3 (B)
E2S: SW402.S1, U406.4 (SWI)
E3A: SW403.A, U407.2 (A)
E3B: SW403.B, U407.3 (B)
E3S: SW403.S1, U407.4 (SWI)
E4A: SW404.A, U408.2 (A)
E4B: SW404.B, U408.3 (B)
E4S: SW404.S1, U408.4 (SWI)
E5A: SW405.A, U409.2 (A)
E5B: SW405.B, U409.3 (B)
E5S: SW405.S2, U409.4 (SWI)
E6A: SW406.A, U410.2 (A)
E6B: SW406.B, U410.3 (B)
E6S: SW406.S2, U410.4 (SWI)
E7A: SW407.A, U411.2 (A)
E7B: SW407.B, U411.3 (B)
E7S: SW407.S2, U411.4 (SWI)
E8A: SW408.A, U412.2 (A)
E8B: SW408.B, U412.3 (B)
E8S: SW408.S2, U412.4 (SWI)
E9A: SW409.A, U413.2 (A)
E9B: SW409.B, U413.3 (B)
E9S: SW409.S2, U413.4 (SWI)
EEP_WP: J104.4, R115.2, U107.7 (WP)
EGND: C401.2, C402.2, C403.2, C404.2, C405.2, C406.2, C407.2, C408.2, C409.2, C410.2, C411.2, C412.2, C413.2, C414.2, C415.2, C416.2, C417.2, C418.2, C419.2, C420.2, C421.2, C422.2, C423.2, C424.2, C425.2, DS301.8 (GND), DS301.13 (GND), DS302.8 (GND), DS302.13 (GND), DS303.8 (GND), DS303.13 (GND), DS304.8 (GND), DS304.13 (GND), DS305.8 (GND), DS305.13 (GND), J310.1, R401.1, R402.1, R403.1, R404.1, R405.1, R406.1, R407.1, R408.1, R409.1, R410.1, SW400.C, SW400.S2, SW401.C, SW401.S2, SW402.C, SW402.S2, SW403.C, SW403.S2, SW404.C, SW404.S2, SW405.C, SW405.S1, SW406.C, SW406.S1, SW407.C, SW407.S1, SW408.C, SW408.S1, SW409.C, SW409.S1, SW410.1 (A), SW411.2 (B), SW412.1 (A), SW413.2 (B), SW414.2 (B), SW415.1 (A), SW416.2 (B), SW417.1 (A), SW418.2 (B), SW419.2 (B), U401.10 (VSS), U401.15 (A0), U401.16 (A1), U401.17 (A2), U402.10 (VSS), U402.15 (A0), U402.16 (A1), U402.17 (A2), U403.10 (VSS), U403.15 (A0), U403.16 (A1), U403.17 (A2), U404.8 (GND), U405.8 (GND), U406.8 (GND), U407.8 (GND), U408.8 (GND), U409.8 (GND), U410.8 (GND), U411.8 (GND), U412.8 (GND), U413.8 (GND), U414.1 (GND), U415.1 (GND), U416.1 (GND), U417.1 (GND), U418.1 (GND), U419.1 (GND), U421.1 (GND), U422.1 (GND), U423.1 (GND)
ENC0-0: D4000.1 (K), U414.5 (OUT0)
ENC0-1: D4001.1 (K), U414.6 (OUT1)
ENC0-2: D4002.1 (K), U414.7 (OUT2)
ENC0-3: D4003.1 (K), U414.8 (OUT3)
ENC0-4: D4004.1 (K), U414.9 (OUT4)
ENC0-5: D4005.1 (K), U414.10 (OUT5)
ENC0-6: D4006.1 (K), U414.11 (OUT6)
ENC0-7: D4007.1 (K), U414.12 (OUT7)
ENC0-8: D4008.1 (K), U414.20 (OUT15)
ENC0-9: D4009.1 (K), U414.19 (OUT14)
ENC0-10: D4010.1 (K), U414.18 (OUT13)
ENC0-11: D4011.1 (K), U414.17 (OUT12)
ENC0-12: D4012.1 (K), U414.16 (OUT11)
ENC0-13: D4013.1 (K), U414.15 (OUT10)
ENC0-14: D4014.1 (K), U414.14 (OUT9)
ENC0-15: D4015.1 (K), U414.13 (OUT8)
ENC1-0: D4016.1 (K), U415.5 (OUT0)
ENC1-1: D4017.1 (K), U415.6 (OUT1)
ENC1-2: D4018.1 (K), U415.7 (OUT2)
ENC1-3: D4019.1 (K), U415.8 (OUT3)
ENC1-4: D4020.1 (K), U415.9 (OUT4)
ENC1-5: D4021.1 (K), U415.10 (OUT5)
ENC1-6: D4022.1 (K), U415.11 (OUT6)
ENC1-7: D4023.1 (K), U415.12 (OUT7)
ENC1-8: D4024.1 (K), U415.20 (OUT15)
ENC1-9: D4025.1 (K), U415.19 (OUT14)
ENC1-10: D4026.1 (K), U415.18 (OUT13)
ENC1-11: D4027.1 (K), U415.17 (OUT12)
ENC1-12: D4028.1 (K), U415.16 (OUT11)
ENC1-13: D4029.1 (K), U415.15 (OUT10)
ENC1-14: D4030.1 (K), U415.14 (OUT9)
ENC1-15: D4031.1 (K), U415.13 (OUT8)
ENC2-0: D4032.1 (K), U416.5 (OUT0)
ENC2-1: D4033.1 (K), U416.6 (OUT1)
ENC2-2: D4034.1 (K), U416.7 (OUT2)
ENC2-3: D4035.1 (K), U416.8 (OUT3)
ENC2-4: D4036.1 (K), U416.9 (OUT4)
ENC2-5: D4037.1 (K), U416.10 (OUT5)
ENC2-6: D4038.1 (K), U416.11 (OUT6)
ENC2-7: D4039.1 (K), U416.12 (OUT7)
ENC2-8: D4040.1 (K), U416.20 (OUT15)
ENC2-9: D4041.1 (K), U416.19 (OUT14)
ENC2-10: D4042.1 (K), U416.18 (OUT13)
ENC2-11: D4043.1 (K), U416.17 (OUT12)
ENC2-12: D4044.1 (K), U416.16 (OUT11)
ENC2-13: D4045.1 (K), U416.15 (OUT10)
ENC2-14: D4046.1 (K), U416.14 (OUT9)
ENC2-15: D4047.1 (K), U416.13 (OUT8)
ENC3-0: D4048.1 (K), U417.5 (OUT0)
ENC3-1: D4049.1 (K), U417.6 (OUT1)
ENC3-2: D4050.1 (K), U417.7 (OUT2)
ENC3-3: D4051.1 (K), U417.8 (OUT3)
ENC3-4: D4052.1 (K), U417.9 (OUT4)
ENC3-5: D4053.1 (K), U417.10 (OUT5)
ENC3-6: D4054.1 (K), U417.11 (OUT6)
ENC3-7: D4055.1 (K), U417.12 (OUT7)
ENC3-8: D4056.1 (K), U417.20 (OUT15)
ENC3-9: D4057.1 (K), U417.19 (OUT14)
ENC3-10: D4058.1 (K), U417.18 (OUT13)
ENC3-11: D4059.1 (K), U417.17 (OUT12)
ENC3-12: D4060.1 (K), U417.16 (OUT11)
ENC3-13: D4061.1 (K), U417.15 (OUT10)
ENC3-14: D4062.1 (K), U417.14 (OUT9)
ENC3-15: D4063.1 (K), U417.13 (OUT8)
ENC4-0: D4064.1 (K), U418.5 (OUT0)
ENC4-1: D4065.1 (K), U418.6 (OUT1)
ENC4-2: D4066.1 (K), U418.7 (OUT2)
ENC4-3: D4067.1 (K), U418.8 (OUT3)
ENC4-4: D4068.1 (K), U418.9 (OUT4)
ENC4-5: D4069.1 (K), U418.10 (OUT5)
ENC4-6: D4070.1 (K), U418.11 (OUT6)
ENC4-7: D4071.1 (K), U418.12 (OUT7)
ENC4-8: D4072.1 (K), U418.20 (OUT15)
ENC4-9: D4073.1 (K), U418.19 (OUT14)
ENC4-10: D4074.1 (K), U418.18 (OUT13)
ENC4-11: D4075.1 (K), U418.17 (OUT12)
ENC4-12: D4076.1 (K), U418.16 (OUT11)
ENC4-13: D4077.1 (K), U418.15 (OUT10)
ENC4-14: D4078.1 (K), U418.14 (OUT9)
ENC4-15: D4079.1 (K), U418.13 (OUT8)
ENC5-0: D4080.1 (K), U419.5 (OUT0)
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

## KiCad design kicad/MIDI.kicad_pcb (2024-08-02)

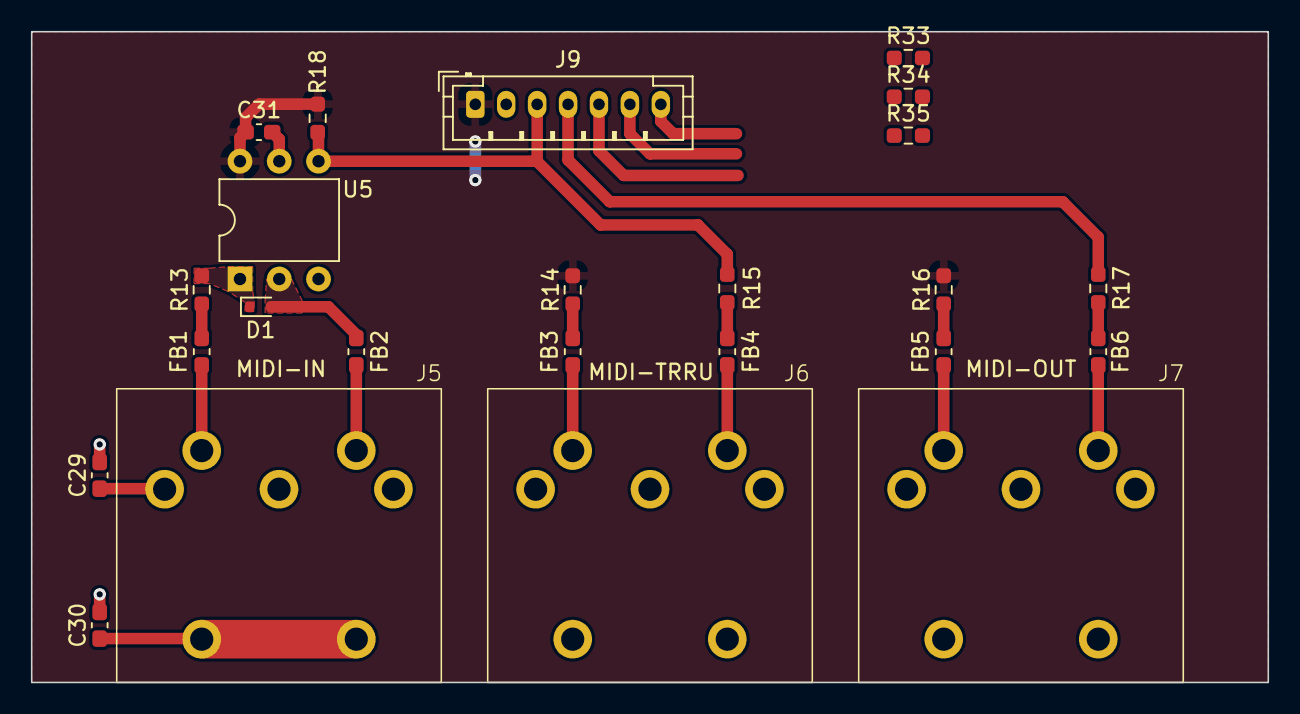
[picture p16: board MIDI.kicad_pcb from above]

Board: 2 copper layers, 80.0 x 42.1 mm, 24 parts (0 on the bottom side), 22 nets.

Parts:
C29, C30, C31: 100nf; C_0603_1608Metric_Pad1.08x0.95mm_HandSolder
D1: 1N914; D_SOD-523
FB1, FB2, FB3, FB4, FB5, FB6: 1K@100MHz; L_0603_1608Metric_Pad1.05x0.95mm_HandSolder
J5, J6, J7: DIN-5_180degree; DIN5-180
J9: Conn_01x07_Socket; JST_PH_B7B-PH-K_1x07_P2.00mm_Vertical
R13: 220; R_0603_1608Metric_Pad0.98x0.95mm_HandSolder
R14, R16: 33; R_0603_1608Metric_Pad0.98x0.95mm_HandSolder
R15, R17: 10; R_0603_1608Metric_Pad0.98x0.95mm_HandSolder
R18: 470; R_0603_1608Metric_Pad0.98x0.95mm_HandSolder
R33, R34, R35: 10K; R_0603_1608Metric_Pad0.98x0.95mm_HandSolder
U5: H11L1; DIP-6_W7.62mm

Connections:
+3V3: C31.1, J9.1, R14.2, R16.2, R18.2, U5.6
GND: C29.2, C30.2, C31.2, J6.2, J6.6, J7.2, J7.6, J9.2, U5.5
M-FPEDAL1: J9.7, R35.1
M-FSW1: J9.5, R33.1
M-FSW2: J9.6, R34.1
M-MIDI_RX: J9.3, R15.2, R18.1, U5.4
M-MIDI_TX: J9.4, R17.2
unnamed: C29.1, J5.2
unnamed: C30.1, J5.6
unnamed: D1.2 (A), FB2.1, U5.2
unnamed: D1.1 (K), R13.2, U5.1
unnamed: FB1.1, R13.1
unnamed: FB1.2, J5.4
unnamed: FB2.2, J5.5
unnamed: FB3.1, R14.1
unnamed: FB3.2, J6.4
unnamed: FB4.1, R15.1
unnamed: FB4.2, J6.5
unnamed: FB5.1, R16.1
unnamed: FB5.2, J7.4
unnamed: FB6.1, R17.1
unnamed: FB6.2, J7.5

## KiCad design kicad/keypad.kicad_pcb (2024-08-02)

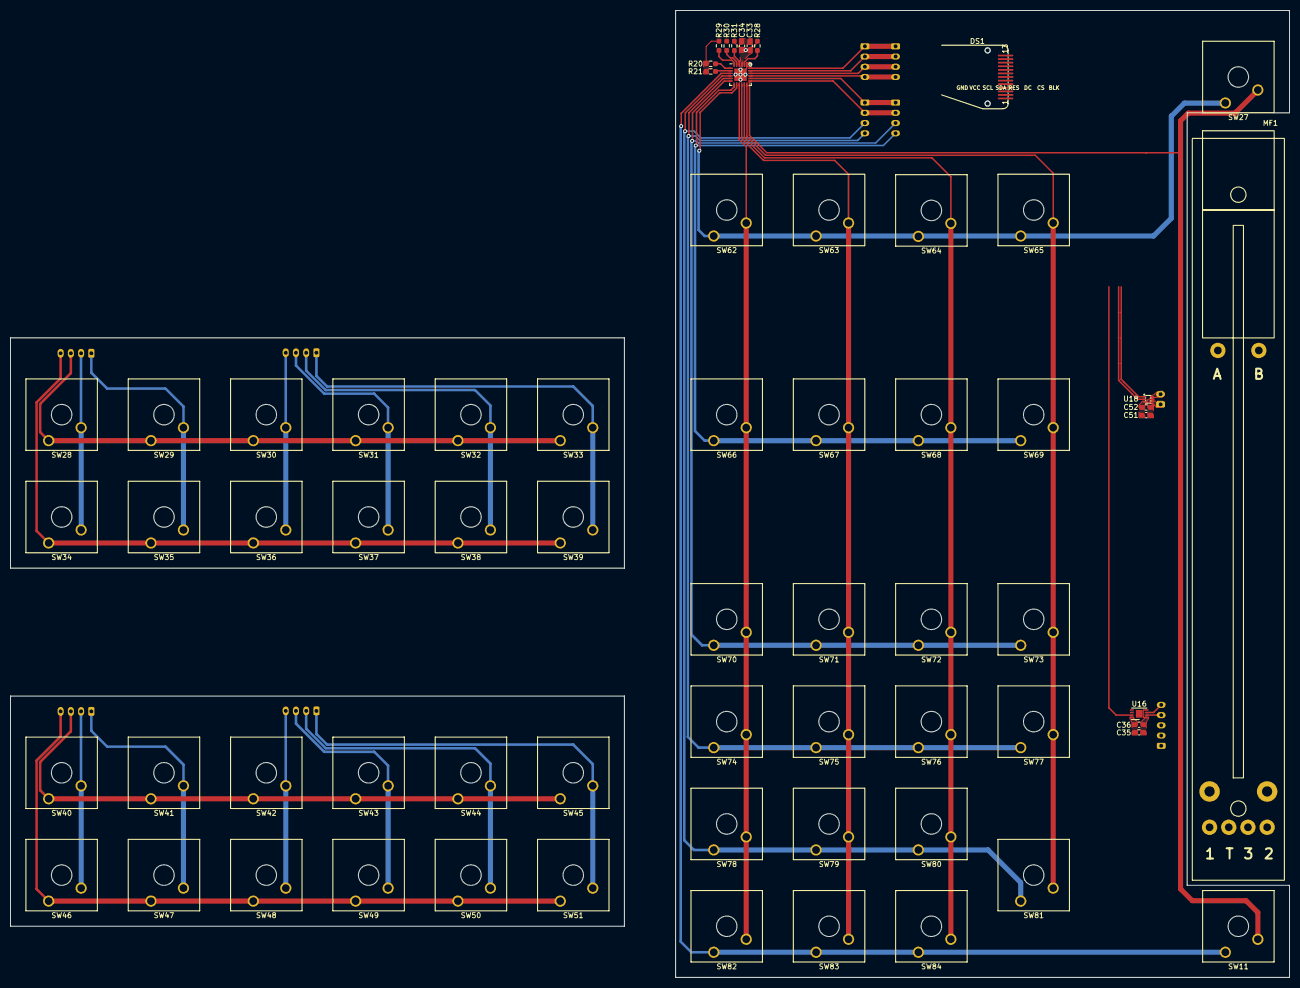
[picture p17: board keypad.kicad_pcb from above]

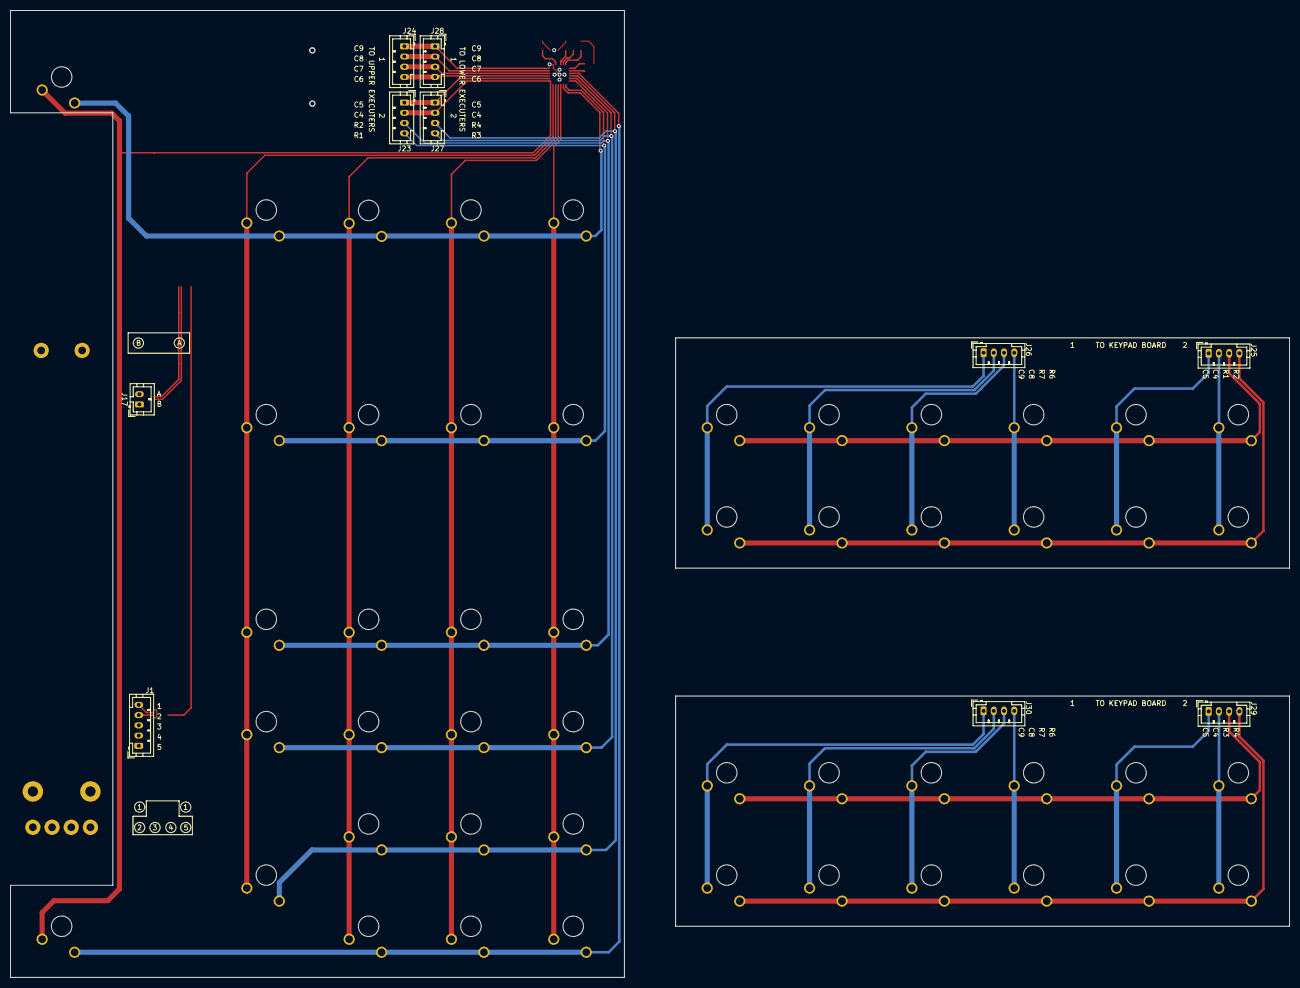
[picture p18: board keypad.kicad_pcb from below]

Board: 2 copper layers, 250.0 x 189.0 mm, 76 parts (10 on the bottom side), 45 nets.

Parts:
C33, C35: 1u; C_0603_1608Metric_Pad1.08x0.95mm_HandSolder
C34, C36, C52: 100n; C_0603_1608Metric_Pad1.08x0.95mm_HandSolder
C51: 100u; C_0603_1608Metric_Pad1.08x0.95mm_HandSolder
DS1: 1.05" 130*240 spi screen; 1.05' 120x240 spi screen
J1: Conn_01x05_Socket; JST_PH_B5B-PH-K_1x05_P2.00mm_Vertical
J17: Conn_01x02_Socket; JST_PH_B2B-PH-K_1x02_P2.00mm_Vertical
J23, J24, J25, J26, J27, J28, J29, J30: Conn_01x04_Socket; JST_PH_B4B-PH-K_1x04_P2.00mm_Vertical
MF1: RSA0N11M9A0J
R20, R21: 10K; R_0603_1608Metric_Pad0.98x0.95mm_HandSolder
R28, R29, R30, R31: 4K7; R_0603_1608Metric_Pad0.98x0.95mm_HandSolder
SW11, SW27, SW28, SW29, SW30, SW31, SW32, SW33, SW34, SW35, SW36, SW37, SW38, SW39, SW40, SW41, SW42, SW43, SW44, SW45, SW46, SW47, SW48, SW49, SW50, SW51, SW62, SW63, SW64, SW65, SW66, SW67, SW68, SW69, SW70, SW71, SW72, SW73, SW74, SW75, SW76, SW77, SW78, SW79, SW80, SW82, SW83, SW84: SW_SPST; SW_Cherry_MX_1.00u_Plate
SW81: SW_SPST; SW_Cherry_MX_2.00u_Vertical_Plate
U7: TCA8418; WQFN-24-1EP_4x4mm_P0.5mm_EP2.45x2.45mm
U16: MTCH102; DFN-8-1EP_3x2mm_P0.5mm_EP1.3x1.5mm
U18: DRV8210; SOT-6

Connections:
+3V3: C33.1, C34.1, C35.1, C36.1, DS1.2 (VCC), J1.2, R20.1, R21.1, R28.1, R29.1, R30.1, R31.1, U7.21 (VCC), U16.1 (VCC), U16.4 (LPMS)
/INT-KEYP: R29.2, U7.24 (~INT)
/RST-KEYP: R28.2, U7.20 (~RESET)
/SCL-KEYP: R30.2, U7.23 (SCL)
/SDA-KEYP: R31.2, U7.22 (SDA)
COL0: SW62.2 (B), SW66.2 (B), SW70.2 (B), SW74.2 (B), SW78.2 (B), SW82.2 (B), U7.9 (COL0)
COL1: SW63.2 (B), SW67.2 (B), SW71.2 (B), SW75.2 (B), SW79.2 (B), SW83.2 (B), U7.10 (COL1)
COL2: SW64.2 (B), SW68.2 (B), SW72.2 (B), SW76.2 (B), SW80.2 (B), SW84.2 (B), U7.11 (COL2)
COL3: SW65.2 (B), SW69.2 (B), SW73.2 (B), SW77.2 (B), SW81.2 (B), U7.12 (COL3)
COL4: J23.2, J27.2, SW11.2 (B), SW27.2 (B), U7.13 (COL4)
COL5: J23.1, J27.1, U7.14 (COL5)
COL6: J24.4, J28.4, U7.15 (COL6)
COL7: J24.3, J28.3, U7.16 (COL7)
COL8: J24.2, J28.2, U7.17 (COL8)
COL9: J24.1, J28.1, U7.18 (COL9)
GND: C33.2, C34.2, C35.2, C36.2, C51.2, C52.2, DS1.1 (GND), J1.3, U7.19 (GND), U16.8 (GND), U18.3 (GND)
MF-G: J1.5, U16.3 (T1/AG)
MF-T: J1.4, U16.2 (T0)
MFA: J17.1, U18.4 (O2)
MFB: J17.2, U18.6 (O1)
unnamed: R21.2, U7.2 (ROW6)
unnamed: R20.2, U7.1 (ROW7)
ROW0: SW27.1 (A), SW62.1 (A), SW63.1 (A), SW64.1 (A), SW65.1 (A), U7.8 (ROW0)
ROW1: J23.4, SW66.1 (A), SW67.1 (A), SW68.1 (A), SW69.1 (A), U7.7 (ROW1)
ROW2: J23.3, SW70.1 (A), SW71.1 (A), SW72.1 (A), SW73.1 (A), U7.6 (ROW2)
ROW3: J27.4, SW74.1 (A), SW75.1 (A), SW76.1 (A), SW77.1 (A), U7.5 (ROW3)
ROW4: J27.3, SW78.1 (A), SW79.1 (A), SW80.1 (A), SW81.1 (A), U7.4 (ROW4)
ROW5: SW11.1 (A), SW82.1 (A), SW83.1 (A), SW84.1 (A), U7.3 (ROW5)
VFMOT: C51.1, C52.1, U18.5 (MVCC)
exe1-COL4: J25.2, SW28.2 (B), SW34.2 (B)
exe1-COL5: J25.1, SW29.2 (B), SW35.2 (B)
exe1-COL6: J26.4, SW30.2 (B), SW36.2 (B)
exe1-COL7: J26.3, SW31.2 (B), SW37.2 (B)
exe1-COL8: J26.2, SW32.2 (B), SW38.2 (B)
exe1-COL9: J26.1, SW33.2 (B), SW39.2 (B)
exe1-ROW1: J25.3, SW28.1 (A), SW29.1 (A), SW30.1 (A), SW31.1 (A), SW32.1 (A), SW33.1 (A)
exe1-ROW2: J25.4, SW34.1 (A), SW35.1 (A), SW36.1 (A), SW37.1 (A), SW38.1 (A), SW39.1 (A)
exe2-COL4: J29.2, SW40.2 (B), SW46.2 (B)
exe2-COL5: J29.1, SW41.2 (B), SW47.2 (B)
exe2-COL6: J30.4, SW42.2 (B), SW48.2 (B)
exe2-COL7: J30.3, SW43.2 (B), SW49.2 (B)
exe2-COL8: J30.2, SW44.2 (B), SW50.2 (B)
exe2-COL9: J30.1, SW45.2 (B), SW51.2 (B)
exe2-ROW3: J29.3, SW40.1 (A), SW41.1 (A), SW42.1 (A), SW43.1 (A), SW44.1 (A), SW45.1 (A)
exe2-ROW4: J29.4, SW46.1 (A), SW47.1 (A), SW48.1 (A), SW49.1 (A), SW50.1 (A), SW51.1 (A)

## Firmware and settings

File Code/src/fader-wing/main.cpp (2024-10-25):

#include <stdio.h>
#include "hardware/gpio.h"
#include "hardware/spi.h"
#include "pico/time.h"
#include "pico/stdlib.h"
#include <encoder.h>


#define spi_port spi0
#define TX_PIN 19
#define CLK_PIN 18
#define LATCH_PIN 20
#define BLANK_PIN 21


void pulse(int pin) {
    gpio_put(pin, 1);
    sleep_ms(1);
    gpio_put(pin, 0);
}

void set_led_pattern(uint8_t *pattern, size_t len) {
    gpio_put(LATCH_PIN, 0);
    gpio_put(BLANK_PIN, 1); // Turn off all LEDs

    spi_write_blocking(spi_port, pattern, len);

    gpio_put(LATCH_PIN, 1);
    gpio_put(LATCH_PIN, 0);
    gpio_put(BLANK_PIN, 0); // Enable LED drivers
}

void demo_static_pattern() {
    uint8_t buf[2] = {0b10101010, 0b01010101}; // Example static pattern with alternating LEDs
    set_led_pattern(buf, sizeof(buf));
}

void demo_moving_light() {
    uint8_t buf[2];
    for (int i = 0; i < 8; i++) {
        buf[0] = 1 << i; // Move one bit in the first byte
        buf[1] = 0;      // Second byte is off
        set_led_pattern(buf, sizeof(buf));
        sleep_ms(100);
    }
}

void demo_chase_pattern() {
    uint8_t buf[2];
    for (int i = 0; i < 16; i++) {
        buf[0] = 1 << i; // Chase pattern in the first byte
        buf[1] = 0;      // Second byte is off
        set_led_pattern(buf, sizeof(buf));
        sleep_ms(100);
    }
    for (int i = 14; i >= 0; i--) { // Chase backwards
        buf[0] = 1 << i;
        buf[1] = 0;
        set_led_pattern(buf, sizeof(buf));
        sleep_ms(100);
    }
}

void demo_blinking_pattern() {
    uint8_t buf[2] = {0b11111111, 0b11111111}; // All LEDs on
    set_led_pattern(buf, sizeof(buf));
    sleep_ms(500);
    buf[0] = 0;
    buf[1] = 0; // All LEDs off
    set_led_pattern(buf, sizeof(buf));
    sleep_ms(500);
}

int main() {

    gpio_init(PICO_DEFAULT_LED_PIN);
    gpio_set_dir(PICO_DEFAULT_LED_PIN, GPIO_OUT);
    gpio_put(PICO_DEFAULT_LED_PIN, 1);

    gpio_init(LATCH_PIN);
    gpio_init(BLANK_PIN);
    //gpio_init(TX_PIN);
    //gpio_init(CLK_PIN);
    gpio_set_dir(LATCH_PIN, GPIO_OUT);
    gpio_set_dir(BLANK_PIN, GPIO_OUT);
    //gpio_set_dir(TX_PIN, GPIO_OUT);
    //gpio_set_dir(CLK_PIN, GPIO_OUT);


    gpio_set_function(CLK_PIN, GPIO_FUNC_SPI);
    spi_init(spi_port, 1000000);
    gpio_set_function(TX_PIN, GPIO_FUNC_SPI);

    gpio_put(LATCH_PIN, 0);
    gpio_put(BLANK_PIN, 1); // turn off all leds

    uint8_t buf[2];

    buf[0] = 0b01110111;
    buf[1] = 0b11011101;



    spi_write_blocking(spi_port, buf, 2);
    gpio_put(LATCH_PIN, 1);
    gpio_put(LATCH_PIN, 0);

    gpio_put(BLANK_PIN, 0); //enalble led drivers




    while (true) {
        demo_static_pattern();
        sleep_ms(1000);

        demo_moving_light();
        sleep_ms(1000);

        demo_chase_pattern();
        sleep_ms(1000);

        demo_blinking_pattern();
        sleep_ms(1000);
    }

    return 0;
}

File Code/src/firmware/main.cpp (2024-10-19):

#include <stdio.h>
#include "hardware/gpio.h"
#include "pico/time.h"
#include "pico/stdlib.h"
//#include "TFT_eSPI/TFT_eSPI.h"

#include <fader.h>
#include <button.h>
// #include <encoder.h> (not yet implemented)



//#define LS30 // uncomment when using the ls30 debounc ic for the encoders (not yet inplemented)



#define FADER_1_A 10
#define FADER_1_B 11
#define FADER_2_A 12
#define FADER_2_B 13





int main () {
    const uint LED_PIN = PICO_DEFAULT_LED_PIN; 
    gpio_init(LED_PIN);
    gpio_set_dir(LED_PIN, GPIO_OUT);

    stdio_init_all(); // usb/uart stdio for printf/debug


    gpio_put(LED_PIN, 1);
    printf("online\n");

    return 0;

};

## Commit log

2024-07-08 added pico-sdk submodule
2024-07-08 add gcc-arm-none-eabi
2024-07-08 test gh actions fail compile
    [main.cpp]
2024-07-09 remove test compile error
    [main.cpp]
2024-08-02 only upload on no error and print firmware location
2024-08-02 started implementing a different pin strategy for the mcp23s17/rp2040
2024-08-02 added kicad and freecad hardware files to repo
    [Fader-Leds.kicad_sch, MIDI.kicad_pcb, MIDI.kicad_sch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]
2024-08-02 readd pico-sdk submodule
2024-08-02 hopefully fixed pico-sdk submodule
2024-08-03 first version of "following fader"
    works but is only sort of smooth at lower voltages and thus lower motor speeds. needs pid later probably. now it is just full speed up or down.
2024-08-03 fixed read_adc result calculation
    [main.cpp]
2024-08-03 removed stupid *0.5 that had me searching for bugs for half an hour
    [main.cpp]
2024-08-07 remove kicad backups from repo
2024-08-07 add kicad backups to gitignore
2024-08-07 removed some more unnessesary kicad files
2024-08-07 remove unnesseary model files from repo
    [midi-test-Body.dxf, midi-test-Body.step, midi-test.dxf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]
2024-08-08 moved Pin to its own folder as it is no longer only part of the mcp23s17
    I Know this wont conpile as it has errors that are caused by moving and
    changing the `Pin` implementation. Will be fixed in next commit.
    [main.cpp, pin.cpp]
2024-08-21 update kicad files
    [Fader-Leds.kicad_sch, faders.kicad_sch, midi-controller.kicad_pcb]
2024-08-22 add tlc59282 datasheet
    and some other small updates to docs
    [model.sync-conflict-20240508-114516-TOB3DYY.FCStd, model.sync-conflict-20240517-162659-TOB3DYY.FCStd]
2024-08-22 add/update some model files
    [midi-test-Body.dxf, midi-test-Body.step, midi-test.dxf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]
2024-08-25 changed the project structure and fixed cmake (hopefully)
    changed the project to have a separeate rp2040 in each fader wing for control there. so i needed 2 binaries that both used the same libraries for components. and after moving those and (what i thought) updating the cmake files everything was fucked. so about an hour and a half later and a all my gpt4o tokes for today i have fixed them
    [main.cpp]
2024-08-27 first version of keycap insert.
    [keycap insert v1.FCStd]
2024-08-27 forgot to also add stl
    [keycap insert v1.stl]
2024-08-27 next iteration
    [keycap insert v1.FCStd, keycap insert v1.stl]
2024-08-27 feat(schem): started implementing the rp2040 on each wing
    [faders.kicad_sch, midi-controller.kicad_sch]
2024-08-27 changed some more of the schematic
    [Fader-Leds.kicad_sch, faders.kicad_sch]
2024-08-27 feat(sch): mostly figured uit pinout for rp2040 and some other small edits
    [faders.kicad_sch]
2024-08-30 feat(pcb): routing tracks from mcu to pheriperals
    [faders.kicad_sch]
2024-09-03 created test stand for faders
    they were annoying to hold in my hands the entire time i need to use them for tests
    [fader test stand.FCStd, keycap insert v1.FCStd]
2024-09-25 continued work on fader pcb and redid all references more logicly
    [Fader-Leds.kicad_sch, MIDI.kicad_sch, USB.kicad_sch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]
2024-09-25 hopefully make the keycap insert fit into standard mx switches
    [keycap insert v1.FCStd]
2024-09-25 added print files from last update
    [keycap insert v1-Body.3mf]
2024-09-25 small updates, add fillet to inside corners and check overall dimentsions
    [keycap insert v1-Body.3mf, keycap insert v1.FCStd]
2024-09-25 fits pretty well. decreased stem lenght to 4mm
    [keycap insert v1.FCStd]
2024-09-28 reorderd model files
    [fader test stand-Body.stl, fader test stand.FCStd, keycap insert v1.FCStd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]
2024-09-28 add first few keycap models
    [keycap 1.stl, keycap 1u +.FCStd, keycap 1u -.FCStd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]
2024-09-28 add user and bank keycap models
    [keycap 1u B1.FCStd, keycap 1u B2.FCStd, keycap 1u B3.FCStd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]
2024-09-28 add blackout and bpm keycap
    [keycap 1u BO.FCStd, keycap 1u BPM.FCStd]
2024-09-28 add arrow (up/down, all directions in one) and bpm
    [keycap 1u BPM.FCStd, keycap 1u arrow.FCStd, keycap 1u blank.FCStd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]
2024-09-28 added executor keycaps
    [keycap 1u X01.FCStd, keycap 1u X02.FCStd, keycap 1u X03.FCStd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]
2024-09-28 found out that model drawing was far out of date on github so here is current version
2024-09-28 Create fader pid control.md
    save url for fader pid control
2024-10-18 Add kicad lock files to .gitignore
2024-10-18 finish updateing all references, add schematic pdf and some more progress
    [Fader-Leds.kicad_sch, faders.kicad_sch]
2024-10-19 add some more unnessesary kicad files to gitignore
2024-10-19 some more progress on the fader pcb and small changes to schematic
    [faders.kicad_sch]
2024-10-20 chose sk6812 mini as led for all the keys, added datasheet
2024-10-20 replaced normal mx footprints to ones that also support hot swap sockets and have leds build in.
    updated schematic and pcb to accomodate this. didn't connect the leds in the footprint yet
    [faders.kicad_sch]
2024-10-20 fix kicad cache exclusion in gitignore
2024-10-20 forgot to add updated pdf to last schematic change
2024-10-24 always touch the main source file so the linker will print the used memory info
2024-10-25 started working on encoder implementation. leds almost finished
2024-10-30 remove some unnessesary files and added 2 new datasheets of the motor faders
2024-10-30 more progress on fader pcb. moved around ls30's to make space for hot swap sockets
    [Fader-Leds.kicad_sch, faders.kicad_sch]
2024-10-30 fix (schematic) : add missing power symbol to encoder leds
    [Fader-Leds.kicad_sch]
2024-10-30 feat (schematic) : link tlc59282's and small edits
    not happy with the link from top right to bottom left. TODO: fix that later
2025-01-29 pushed unsaved kicad files. don't know what changed
    [Fader-Leds.kicad_sch, faders.kicad_sch]
2025-01-30 completely reworked pin implementation
2025-01-30 deprecated old pin implementation
    i know this doesn't compile. will fix the dependant files shortly
